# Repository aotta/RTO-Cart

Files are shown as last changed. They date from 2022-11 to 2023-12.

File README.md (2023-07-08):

# RTO-Cart
Redesigned T-Cart - Multicart for Mattel Intellivision based on Teensy 4.1
It work with bin file loaded on sdcard, with ram/rom mapping from .cfg files with same name in same folder.
If found the [macro] section in the .cfg files, it ask for using the Cheat's pokes (middle button) or ignore them (other button).
File navigation is done with by buttons, while playing button 1 resets the console, button 3 resets the Cart.

You probably don't need mounting the resistor near the edge for reset the console, try yourself and be sure to have a good bipolar cap at reset line in your console! ;) 

More infor on:
https://forums.atariage.com/topic/346024-intellivision-rto-multicart-new-multicart/

User manual added by courtesy of Eskimo/RKOTower

Fixed version for SECAM Intellivision (thanks to zx81zx81):
https://github.com/zx81zx81/RTO-Cart-secam

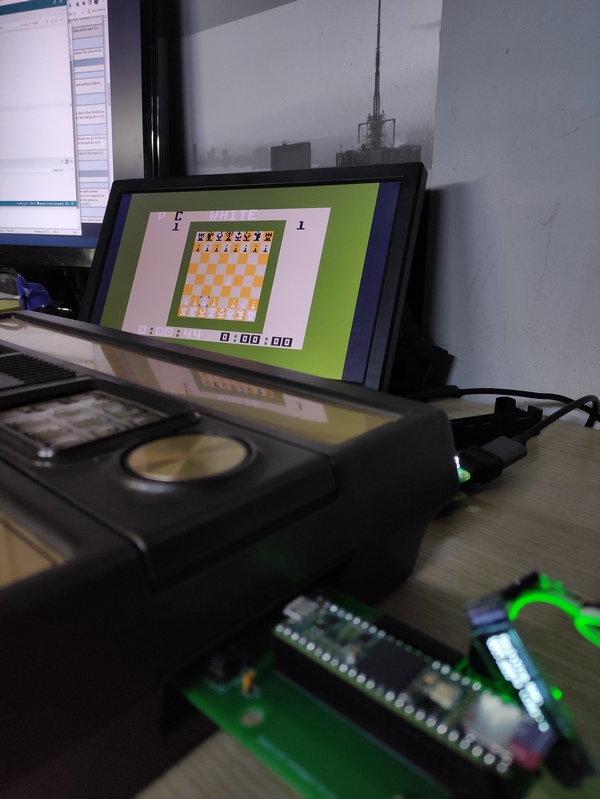
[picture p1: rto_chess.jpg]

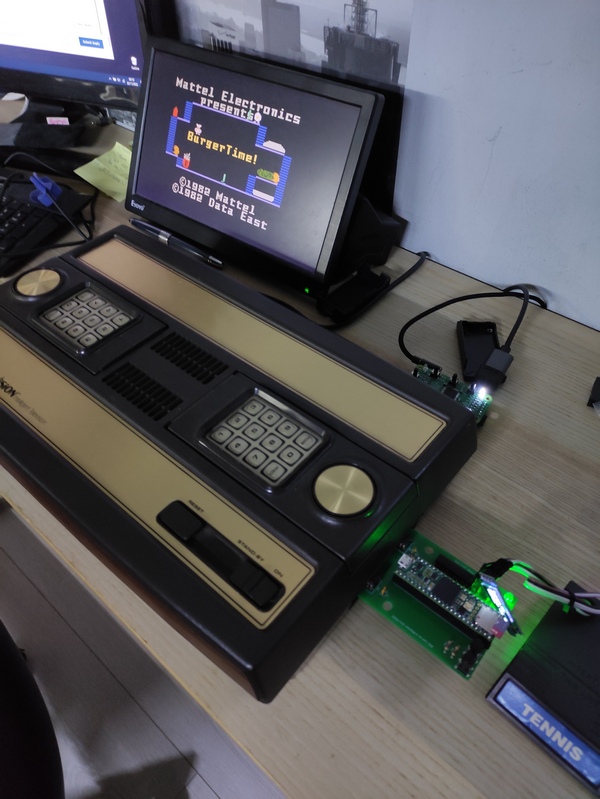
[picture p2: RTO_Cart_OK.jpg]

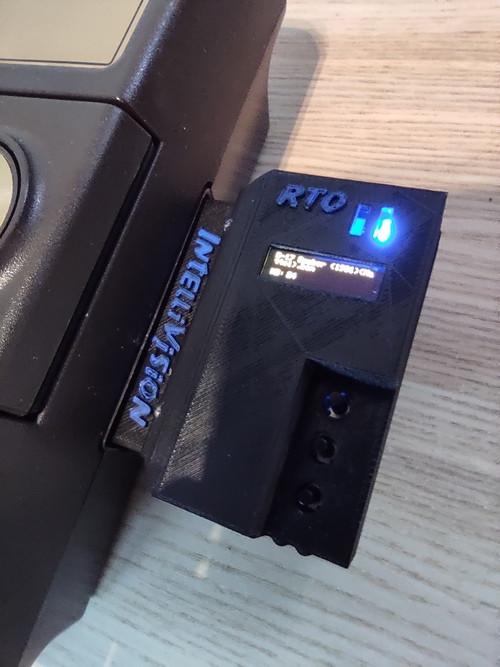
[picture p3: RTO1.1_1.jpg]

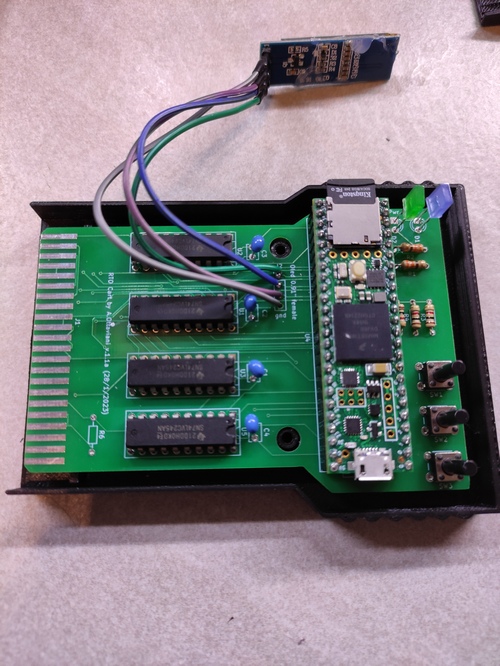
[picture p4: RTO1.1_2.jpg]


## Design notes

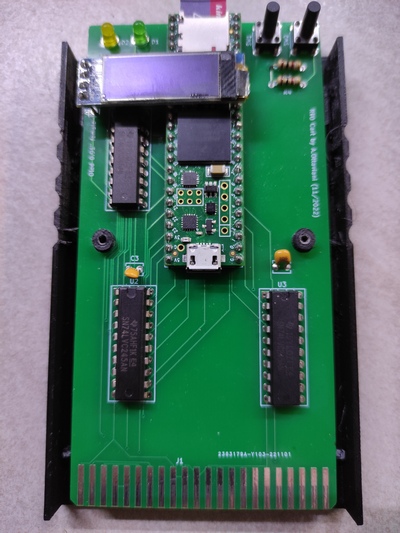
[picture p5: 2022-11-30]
rto_pcb.jpg

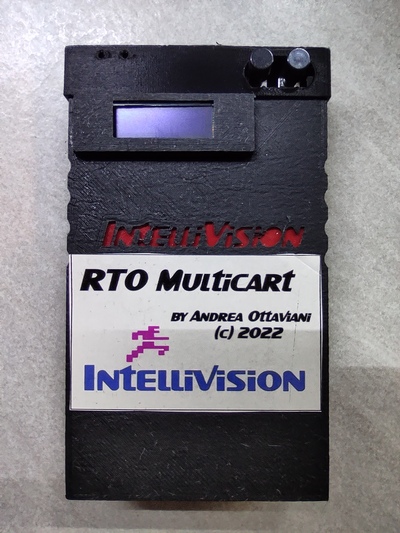
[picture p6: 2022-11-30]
cart2.jpg

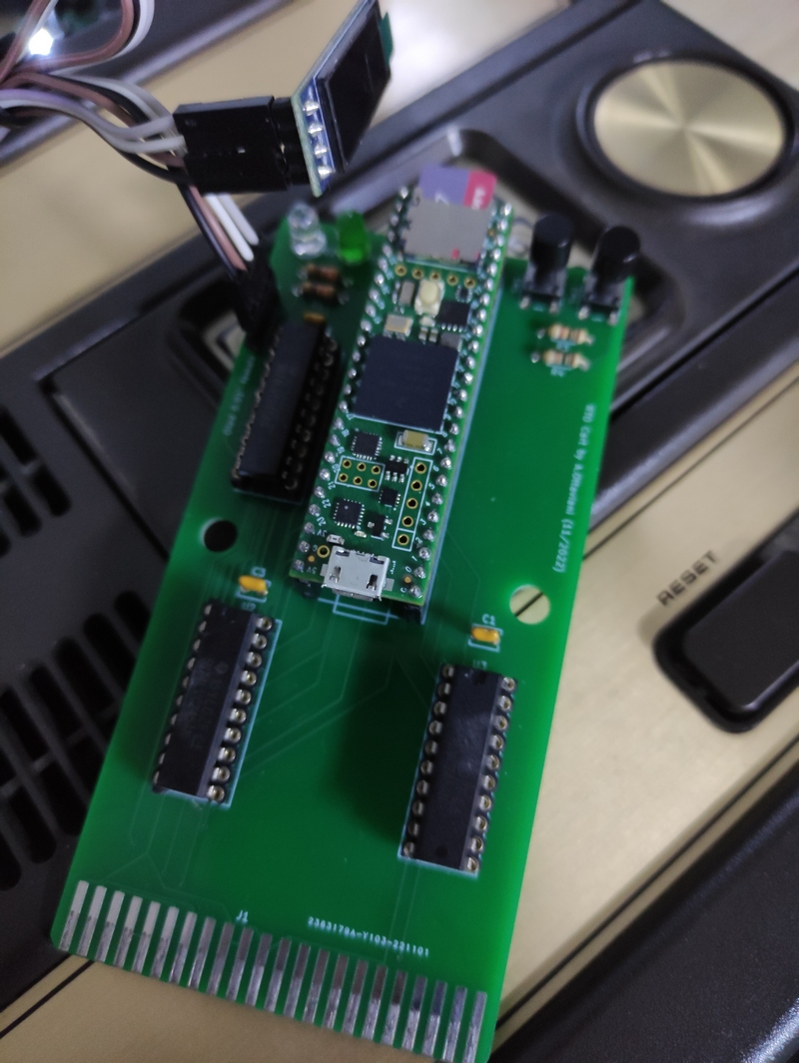
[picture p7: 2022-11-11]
RTO1.png

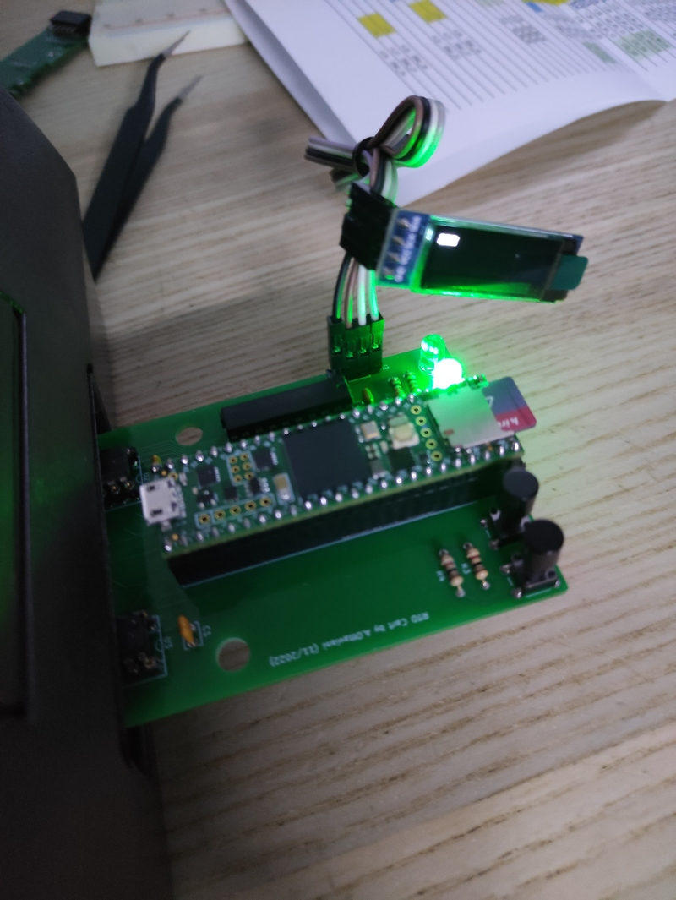
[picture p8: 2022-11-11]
RTO3.png

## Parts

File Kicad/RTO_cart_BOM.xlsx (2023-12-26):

Column1 | Column2 | Column3 | Column4 | Column5 | Column6 | Column7
Component Count: | 22
Individual Components:
Item | Qty | Reference(s) | Value | LibPart | Footprint | Datasheet
 |  | C1 | 100nF | Device:C | Capacitor_THT:C_Disc_D3.8mm_W2.6mm_P2.50mm | ~
 |  | C2 | 100nF | Device:C | Capacitor_THT:C_Disc_D3.8mm_W2.6mm_P2.50mm | ~
 |  | C3 | 100nF | Device:C | Capacitor_THT:C_Disc_D3.8mm_W2.6mm_P2.50mm | ~
 |  | C4 | 100nF | Device:C | Capacitor_THT:C_Disc_D3.8mm_W2.6mm_P2.50mm | ~
 |  | D1 | LED | Device:LED | LED_THT:LED_D3.0mm | ~
 |  | D2 | LED | Device:LED | LED_THT:LED_D3.0mm | ~
 |  | J2 | Oled 0.91" female | Connector:Conn_01x04_Male | Connector_PinHeader_2.54mm:PinHeader_1x04_P2.54mm_Vertical | ~
 |  | R1 | R220 | Device:R | Resistor_THT:R_Axial_DIN0204_L3.6mm_D1.6mm_P7.62mm_Horizontal | ~
 |  | R2 | R220 | Device:R | Resistor_THT:R_Axial_DIN0204_L3.6mm_D1.6mm_P7.62mm_Horizontal | ~
 |  | R3 | 1K | Device:R | Resistor_THT:R_Axial_DIN0204_L3.6mm_D1.6mm_P7.62mm_Horizontal | ~
 |  | R4 | 1K | Device:R | Resistor_THT:R_Axial_DIN0204_L3.6mm_D1.6mm_P7.62mm_Horizontal | ~
 |  | R5 | 1K | Device:R | Resistor_THT:R_Axial_DIN0204_L3.6mm_D1.6mm_P7.62mm_Horizontal | ~
 |  | R6 | 4K7 | Device:R | Resistor_THT:R_Axial_DIN0204_L3.6mm_D1.6mm_P7.62mm_Horizontal | ~
 |  | SW1 | SW_Push | Switch:SW_Push | Button_Switch_THT:SW_PUSH_6mm | ~
 |  | SW2 | SW_Push | Switch:SW_Push | Button_Switch_THT:SW_PUSH_6mm | ~
 |  | SW3 | SW_Push | Switch:SW_Push | Button_Switch_THT:SW_PUSH_6mm | ~
 |  | U1 | 74LVC245 | 74xx:74LS245 | Package_DIP:DIP-20_W7.62mm_Socket | http://www.ti.com/lit/gpn/sn74LS245
 |  | U2 | 74LVC245 | 74xx:74LS245 | Package_DIP:DIP-20_W7.62mm_Socket | http://www.ti.com/lit/gpn/sn74LS245
 |  | U3 | 74LVC245 | 74xx:74LS245 | Package_DIP:DIP-20_W7.62mm_Socket | http://www.ti.com/lit/gpn/sn74LS245
 |  | U4 | Teensy4.1 | teensy:Teensy4.1 | Teensy:Teensy41
 |  | U5 | 74LVC245 | 74xx:74LS245 | Package_DIP:DIP-20_W7.62mm_Socket | http://www.ti.com/lit/gpn/sn74LS245
Collated Components:
Item | Qty | Reference(s) | Value | LibPart | Footprint | Datasheet
1 | 4 | C1, C2, C3, C4 | 100nF | Device:C | Capacitor_THT:C_Disc_D3.8mm_W2.6mm_P2.50mm | ~
2 | 2 | D1, D2 | LED | Device:LED | LED_THT:LED_D3.0mm | ~
3 | 1 | J1 | 2x22 card edge connector | Evan's misc parts:2x22 card edge connector | Evan's misc parts:edge mounted 44 pin card edge connector (2x22 pin) | ~
4 | 1 | J2 | Oled 0.91" female | Connector:Conn_01x04_Male | Connector_PinHeader_2.54mm:PinHeader_1x04_P2.54mm_Vertical | ~
5 | 2 | R1, R2 | R220 | Device:R | Resistor_THT:R_Axial_DIN0204_L3.6mm_D1.6mm_P7.62mm_Horizontal | ~
6 | 3 | R3, R4, R5 | 1K | Device:R | Resistor_THT:R_Axial_DIN0204_L3.6mm_D1.6mm_P7.62mm_Horizontal | ~
7 | 1 | R6 | 4K7 | Device:R | Resistor_THT:R_Axial_DIN0204_L3.6mm_D1.6mm_P7.62mm_Horizontal | ~
8 | 3 | SW1, SW2, SW3 | SW_Push | Switch:SW_Push | Button_Switch_THT:SW_PUSH_6mm | ~
9 | 4 | U1, U2, U3, U5 | 74LVC245 | 74xx:74LS245 | Package_DIP:DIP-20_W7.62mm_Socket | http://www.ti.com/lit/gpn/sn74LS245
10 | 1 | U4 | Teensy4.1 | teensy:Teensy4.1 | Teensy:Teensy41

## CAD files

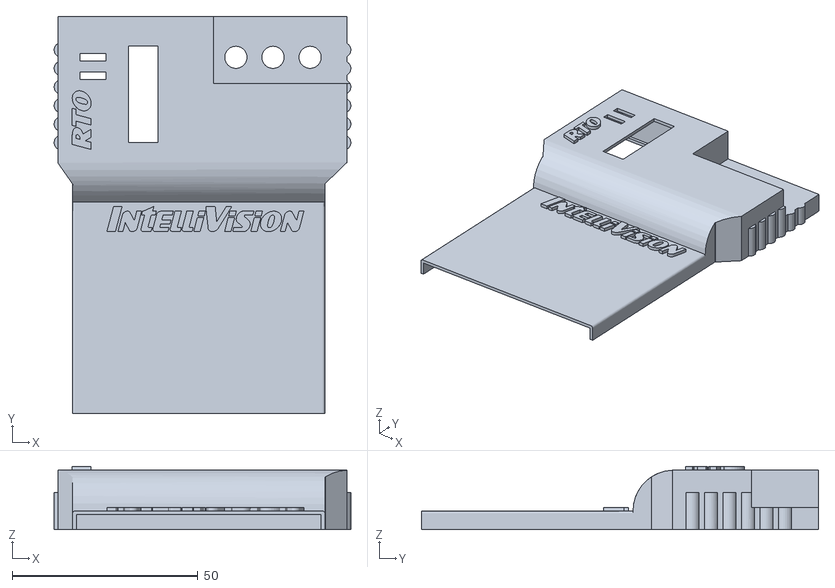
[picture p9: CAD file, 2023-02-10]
3DModel/RTO11a_Cart_TOP.stl
80.0 x 107.0 x 17.0

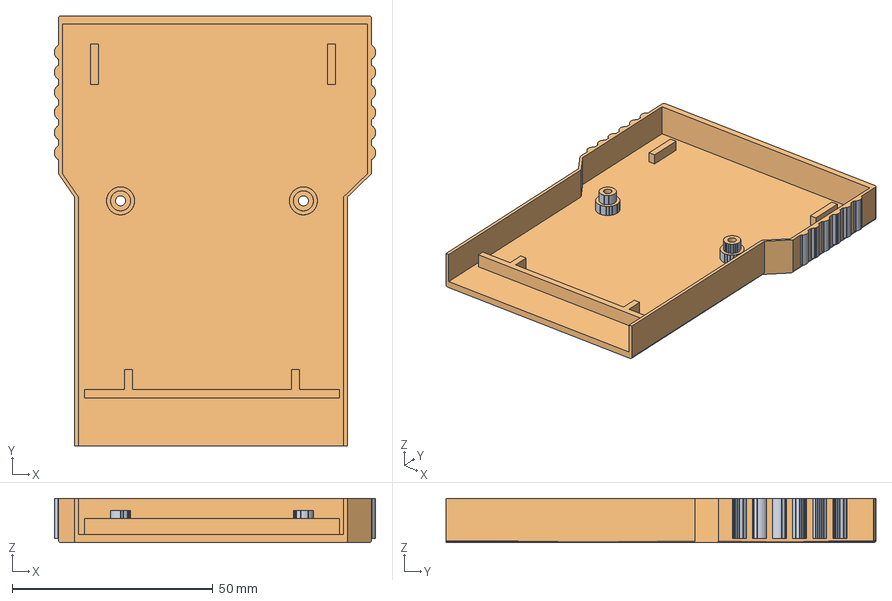
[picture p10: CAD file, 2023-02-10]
3DModel/RTO11a_Cart_Bottom.FCStd
80.0 x 107.0 x 11.0 mm
Bot__final
Refined_Mesh_Solid_81622
Bot__final (Meshed)

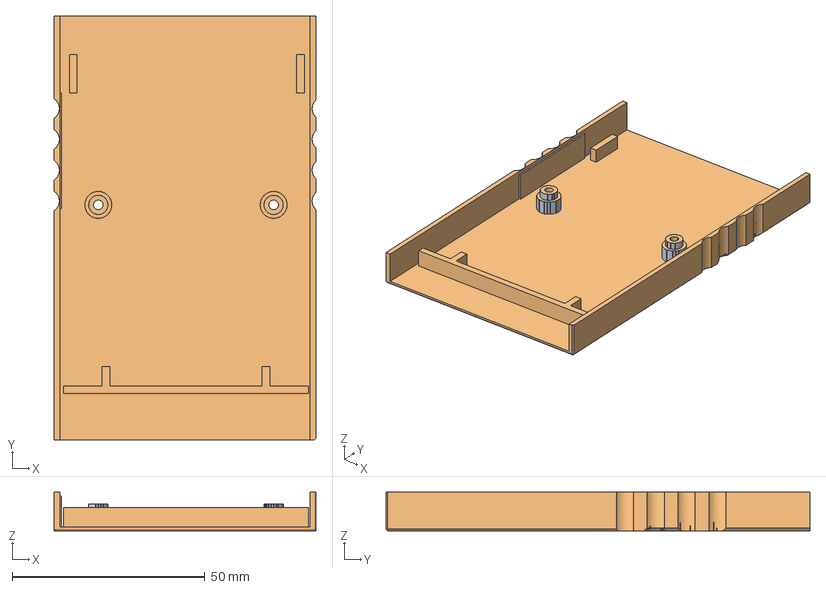
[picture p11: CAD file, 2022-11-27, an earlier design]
old ver/3DModel/RTO_Cart_Bottom.FCStd
68.0 x 110.0 x 10.0 mm
Refined_Mesh_Solid_77860
Chamfer003 (Meshed)

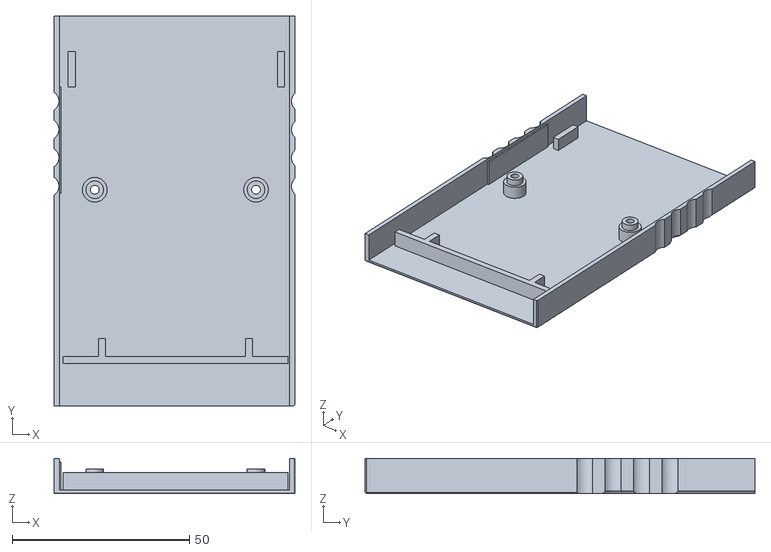
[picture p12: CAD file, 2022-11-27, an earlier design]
old ver/3DModel/RTO_Cart-BOT.stl
68.0 x 110.0 x 10.0

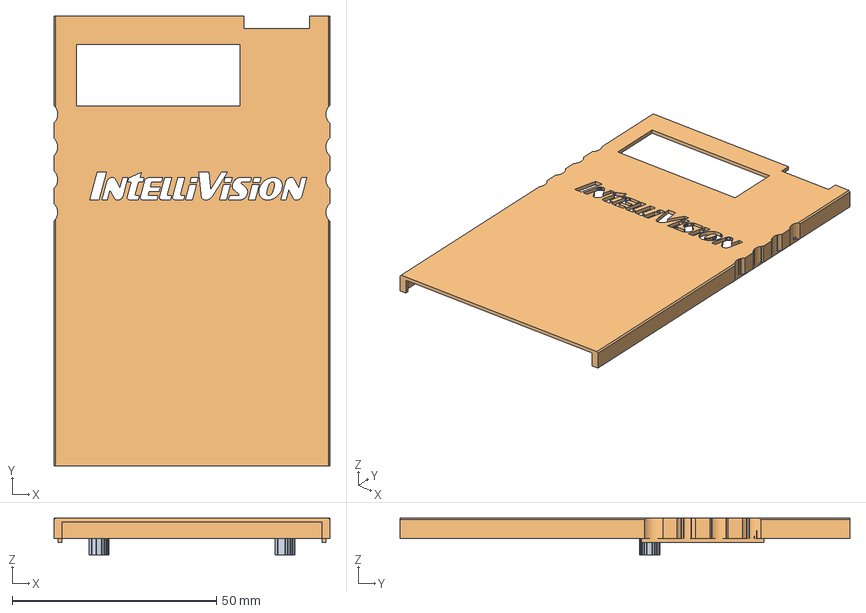
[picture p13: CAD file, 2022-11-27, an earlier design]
old ver/3DModel/RTO_Cart_TOP.FCStd
67.5 x 110.0 x 9.00 mm
Refined_Mesh001_Solid_54728
Chamfer (Meshed)

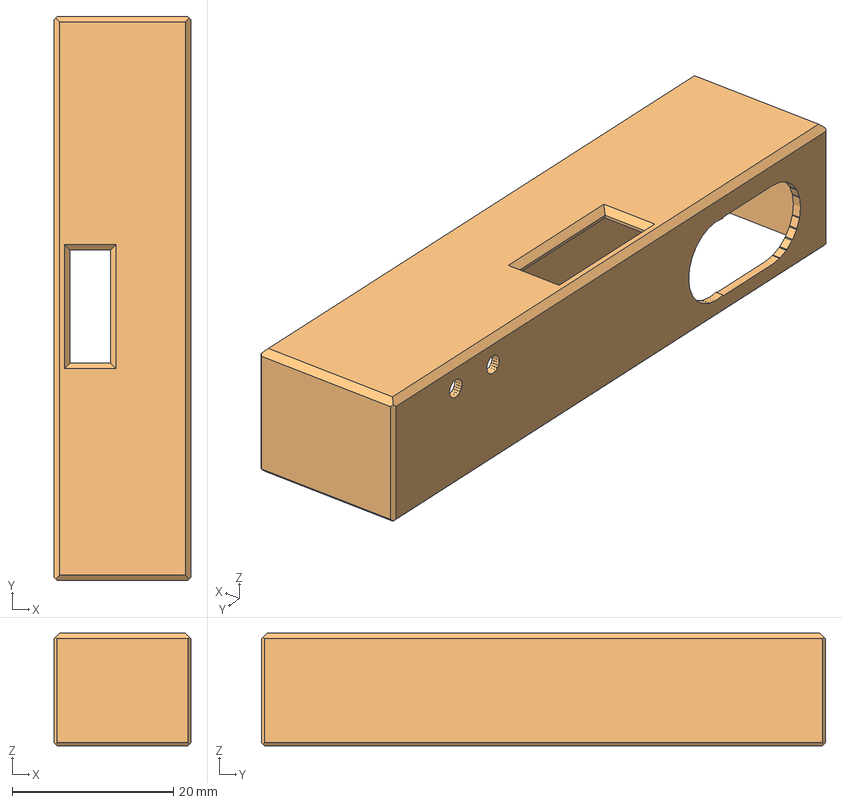
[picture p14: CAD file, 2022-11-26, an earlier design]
old ver/3DModel/RTO_Cart_CUP.FCStd
17.0 x 70.0 x 14.0 mm
Refined_Mesh_Solid_77090
Cut006 (Meshed)

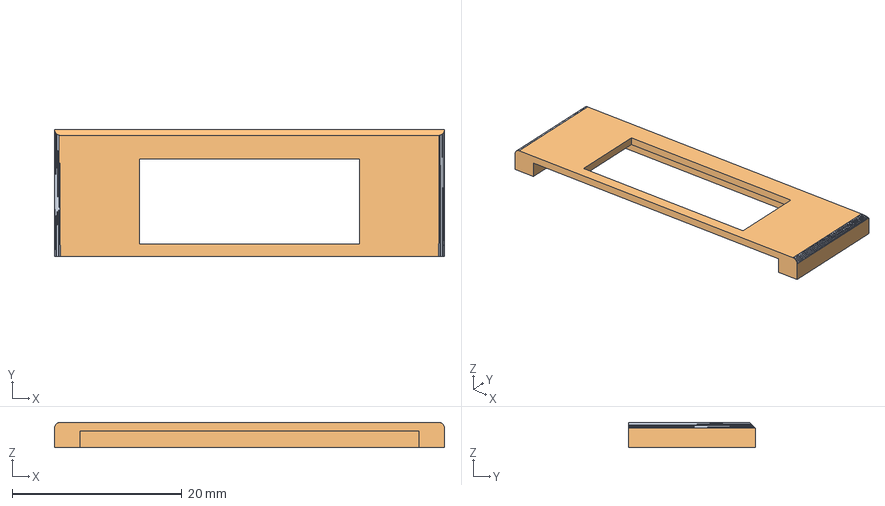
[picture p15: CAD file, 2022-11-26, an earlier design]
old ver/3DModel/RTO_Cart_LCD.FCStd
46.0 x 15.0 x 3.00 mm
Refined_Mesh_Solid_99120
Cut002 (Meshed)

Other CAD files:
3DModel/RTO11a_Cart_Bottom.stl
old ver/3DModel/RTO_Cart_CUP.stl
old ver/3DModel/RTO_Cart_LCD.stl
old ver/3DModel/RTO_Cart_TOP.stl

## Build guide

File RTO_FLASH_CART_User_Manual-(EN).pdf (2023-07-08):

### RTO FLASH CARTRIDGE USER MANUAL

Cartridge Design by Andrea Ottaviani Package Design by Alessandro
User Manual by Eskimo/RKOTower

The hardware cartridge "Intellivision RTO Flash Cart" (henceforth referred to as RTO) allows Program/Game files to be loaded on the Intellivision console; these files are "Cartridge Dumps" i.e. transfers of the programs contained in the ROMs of the Intellivision cartridges.
These files must be stored on a micro SD card, which is inserted into the compartment located to the left of the RTO, and the latter will be inserted into the cartridge port of the console.

TECHNICAL FEATURES

-) Supported console : Mattel Intellivision

-) Compatible type of files : .BIN + .CFG

-) RTO reads files stored on a micro SD

-) Compatible media : micro SD Card from 1 Gb to 32 Gb - FAT and FAT32 formatting

-) Compatible Intellivision Console : PAL/NTSC or SECAM

-) Operations of searching and loading files by three Push Buttons located on the RTO cartridge

-) Titles must be placed in the Root of the micro SD card or, to sort Titles, inside folders placed in the Root of the micro SD card, for example to sort them by alphabetically, by genre etc. - Sub-folders can NOT be used.

-) It needs to be stored in the Root of the micro SD the basic configuration file "0.cfg". See Appendix

-) Folders and file names : Compatible with Long Names, max 45 Characters + extension for files

-) RTO shows the list of folders and files on the OLED display

-) Two LEDs are the indicators of RTO cartridge operation.

-) Direct power supply from the console's cartridge port

IMPORTANT

All connections and disconnections, both electrical and mechanical, must be made with the equipment off and the cables not connected to the mains electrical outlets.

Do not use liquids to clean the RTO cartridge, but only cloths made of antistatic material.The RTO cartridge is composed of electronic parts and its casing is made of PLA or ABS plastic material.

Do not press on the small window that houses the OLED Display, this is a delicate component and pressure can damage it and cause it to come out of its housing creating further damage to other electronic components that are inside the RTO cartridge.

Do not disassemble the RTO cartridge and do not make any repair attempts; these tasks should only be carried out by qualified personnel.

Be careful not to spill liquids on the RTO cartridge, in case of accidental spillage of liquids, do not insert the RTO cartridge into the console, and in case it is inserted, remove the plug from the electrical outlet immediately, and dry the RTO cartridge. Before connecting the RTO cartridge make sure it is completely clean and dry, otherwise repeat the cleaning and drying steps.

The User of the RTO Cartridge is solely responsible in case of damage to People, Animals and Property occurred with the use of the RTO Cartridge; the Hardware Designer, the Author of the Manual and the Vendors are not responsible in case of damage to People, Animals and Property occurred with the use of the RTO Cartridge.

By using the RTO Flash Cartridge for Intellivision, the User agrees to the above conditions.

INTELLIVISION CONSOLE CONNECTION

The RTO cartridge should be inserted directly into the right cartridge port of the console.
Insert the RTO cartridge into the console's cartridge port with the side where the text and LEDs are located facing up.

Tip : Place under the RTO cartridge a stand, a support base, which makes the RTO secure and rigidly stable in its position, this for when Push Buttons are pressed during operations.
This holder prevents the RTO cartridge from flexing with finger pressure on the Push Buttons, thus preventing force on the Intellivision connector contacts and the connector itself.
Bending the cartridge could create false contacts and malfunctions, and in the long run could also damage the Intellivision connector or the RTO cartridge itself, or both.
This expediency is advisable because the RTO works through buttons located on the cartridge itself, whereas standard cartridges are inserted into the port but have no buttons to operate.

INSTRUCTIONS ON THE USE OF RTO CARTRIDGE

Using a Personal Computer (the following directions consider a PC with Windows O.S.) copy the program files with the extension .BIN + .CFG to a micro SD card.
You can create folders (only on the Root) to search and sort your Files, e.g. to sort them by genre, type etc. but you CANNOT create sub-folders, the files can be stored either in the Root or in a folder on the micro SD.
The .BIN file must always be associated with a .CFG file, and they must have the same name.

Example : "Burgertime.bin" + "Burgertime.cfg"

NOTE : In case you transfer only the .BIN file without the .CFG configuration file, then the RTO cartridge, not finding the latter, will use, by default, the configuration file "0.cfg" , which must be transferred to the Root of the micro SD, and obviously it may or may not be compatible with your .BIN file.

In general, the "0.cfg" configuration file is compatible with the vast majority of Roms, but not all.

If the RTO cartridge does not find the associated configuration file neither the "0.cfg" file, then it will not be able to run the Program/Game.

The .BIN file contains the "Dump" of the Roms, i.e., all Program/Game data, while the .CFG file contains information on how the various data areas of the Roms should be allocated in the Intellivision's memory map.

Without this important file, the RTO cartridge would not know where to place the contents of the Rom and would not start the Program/Game.

Obviously the .CFG file must contain the correct data, otherwise RTO cannot run the Program/Game.

There are .CFG files that in addition to containing the parameters for Rom allocation, contain additional data, namely "Hacks".

For example, these "Hacks," may have been added to activate the Infinite Lives on a game, or increase the running time of a "Stage," to activate the character's invulnerability, to select which "Stage" to start from, and so on.

In this case the RTO cartridge recognizes the presence of the "Hacks" added in the .CFG file, and asks if you want to activate them or not.

To activate any "Hacks" you press PB 2 on the RTO, but if you want to start the standard Game without "Hacks" you press one of the other two Push Buttons, either PB 1 or PB 3; the detailed explanation of the RTO Push Buttons and their location can be found in the following paragraphs.

NOTE : The .CFG files containing the "Hacks" are created by console enthusiasts, and made generally for use on Intellivision Computer Emulators, so they may also not be fully compatible with the Intellivision console and RTO.

Tip : For transferring the Files to the micro SD, it is preferable to keep a folder with all Programs/Games on the PC and select all Titles and Folders, then right-click on the first Title or Folder in alphabetical order and select "copy," then place on the micro SD card and select "paste" to begin the transfer.

This procedure makes sure to transfer all Files and Folders by copying them in alphabetical, order so that they are found in the same order on the OLED display of the RTO cartridge.

Similarly when you want to add one or more Programs/Games, the best procedure is to copy them to the folder on the PC that contains the ones already transferred previously, then wipe, i.e., delete all the contents of the micro SD card and transfer all the contents from the folder of the PC to the micro SD card as described above.

This avoids ending up with the latest titles added at the top of the list, or in the middle of existing ones, thus maintaining the alphabetical order on the OLED display of the RTO.

It may happen that by adding Titles on the micro SD that already contains others, these added Titles will be shown first on the OLED display by the RTO.

Of course, there is nothing to prevent you from adding titles progressively and proceeding as you like.

HOW TO NAME FILES

The RTO cartridge handles long names, but in order to avoid non-recognition of a title, it is strongly recommended that titles be simplified as much as possible, for example by avoiding the "Space" between names, and instead use the "Minus - " sign and "Underscore _ ", these symbols are fully supported by the RTO cartridge.
Avoid to include symbols such as "Dot", "Apostrophe", "Comma", "Exclamation/Question marks", "Asterisks", etc. etc. and keep the file name as short as possible; Names up to 45 characters long are supported.

Example : a title such as "Masters of the Universe-The Power of He-Man! (1983) (Mattel).bin" would be best reduced to the following "Masters_o_t_Universe-T_P_o_He-Man-(1983).bin"; the exclamation mark was removed, then simplified and shortened, but it still remains understandable, especially for fans of the Intellivision console who are very familiar with all the titles produced.
You can still leave the original title unchanged without any simplification, as you prefer, always respecting the maximum number of 45 characters
Only in the case where, due to some unsupported character, or a bad combination of characters, the title does not appear on the OLED display of the RTO cartridge (in this case a blank space appears when scrolling forward and backward through the titles) then it can be decided to simplify the title to make it compatible.

Once you have completed preparing the micro SD card you can insert it into the slot located on the left side of the RTO; the micro SD should be inserted with the label facing up, and the electrical contacts facing down.

Now you can insert the RTO into the right cartridge slot of the Intellivision console and then turn on the TV or Monitor and the console.

FUNCTIONS DESCRIPTION OF RTO PUSH BUTTONS

The RTO cartridge has three Push Buttons (PB 1 – PB2 – PB3) to operate and to perform various functions, the diagram below shows the location and the Push Buttons Position :

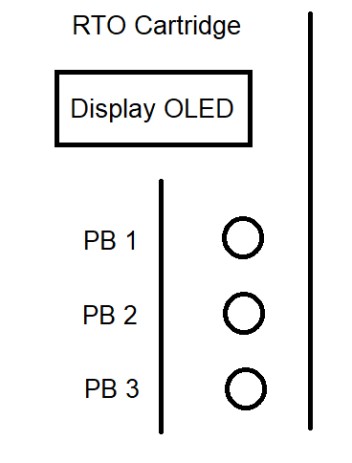
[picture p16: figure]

Functions of the three Push Buttons before starting a Rom on the Intellivision Console

PB 1 - Forward Scrolling Titles and Folders

PB 2 - Enter/Exit a Folder - Starts the selected file (NOTE : to exit from a Folder, use PB 1 or PB 3 to display two exit points with the following characters : " . . Kb:0 " then press PB 2

PB 3 - Backward Scrolling Titles and Folders

Functions of the three Push Buttons while a Program/Game is running on the Console

PB 1 - Reset Intellivision Console (NOTE : If Pushing PB 1 the screen on the TV/Monitor turns black, it means the “Capacitor” on the Reset line of your Intellivision is defective, and to restart the Program/Game that was running you have to press, in addition, the Reset Button on the Intellivision console)

PB 2 - Not Used

PB 3 - Reset Cartridge RTO

When the TV/Monitor and Intellivision console are turned on, the following condition is observed :
The TV/Monitor shows the Main Screen " RTO - Cart Please Select a Game ".
The OLED Display shows the following : " Press a Button on RTO ", use the PB 1 and PB 3 buttons to navigate back and forth through the Titles and Folders, in order to position on the desired Title.
If the Main Screen image does not appear on the TV/Monitor and you have a black screen instead, and also pressing the PB1 and PB 3 buttons they do not work, it means that your console has the "Capacitor" on the "Reset" line defective.

This is not a problem, in fact simply pushing the "Reset" button on the Intellivision, the RTO will be activated, and the Main Screen of the RTO cartridge will appear on the TV/Monitor : " RTO - Cart Please Select a Game ", now you can scroll through the Titles as reported above.

Pushing PB 2 starts a Program/Game or enters in a Folder.

The OLED Display shows the "filename.bin," while the "filename.cfg" is not displayed because it is only for the system and its display has no practical use.

On the OLED display of the RTO in addition to the "filename.bin" the line below shows the size of the ROM in Kb.

Pushing PB 2 will load the ROM into the console and start it.

The OLED display will show the following message : "Emulating ROM : filename.bin" and the Program/Game will start.

If, same as before, the TV/Monitor will remain black without displaying anything, (again due to the defective "Capacitor" mentioned above), to start the Program/Game you must push the Reset button on the Intellivision console.

At this point the control moves to the Intellivision console and you can use all the functions of the "Gamepads" as an original cartridge had been inserted.

By pressing the Reset button on the Intellivision console, the Program/Game will restart, remaining present at all times and behaving as an original cartridge had been inserted.

The same thing is done by pressing PB 1 on the RTO; this button, while the Program/Game is running, has the same function as the Reset button of the Intellivision console.

Pressing the PB 3 instead, while the Program/Game is running, will reset the RTO and remove the Program/Game from the Intellivision console, on the OLED display will appear : "Press a button on RTO", the TV/Monitor will turn black showing nothing more.

At this point the Program/Game is quit and you can proceed to load another one.

In case your Intellivision has the defective "Capacitor", in order to load a new Program/Game you need to do an additional step, in fact pressing any of the 3 buttons nothing happens, then you have to push the Reset button on the Intellivision console, so the Main Screen " RTO - Cart Please Select a Game " will appear on the TV/Monitor.

You can then repeat the above mentioned operations to load a new Program/Game.

INTELLIVISION FILE FORMATS

There are a few formats of the files extracted from Intellivision cartridges, following the three most important ones. All the Cartridges Dumps at least they are available on one of these three formats :

"filename.BIN" | "filename.INT" | "filename.ROM"
1. "filename.BIN" is the classic binary file extracted from the roms contained in Intellivision cartridges, this type of file needs the configuration file "filename.CFG" as described above.
2. “filename.INT” also this is a binary file exactly the same as the previous one, only the extension changes, this type of file needs the configuration file "filename.CFG" as described above. This type of extension was adopted on the Intellivision Emulators, which, probably having to run also on PCs, with Windows O.S., it does not like extension conflicts, in fact the extension .BIN, was already in use on these O.S., and using it could have created association problems with other programs.
3. filename.ROM is the binary file with configuration data included, that is the contents of the "filename.CFG" file, so this type of file does not need the configuration file having it already internally.

As described in the technical features of the RTO cartridge, the only format supported is .BIN, in fact if we transferred files with the extensions .INT and .ROM to the micro SD they would not be showed on the OLED display, and in any case would not be handled.
Let's see how we can handle these two formats and make them compatible with the RTO cartridge.
| filename.INT

For this format the procedure is very simple, just rename the extension from .INT to .BIN
Example : "burgertime.int" renaming the extension will become "burgertime.bin", having done this simple step we treat it exactly like a .BIN file.

filename.ROM

As described before this is an "Embedded" file that it includes the two files "filename.BIN" and "filename.CFG" in the .ROM file.
In order to use it on the RTO cartridge, it is necessary to extract the two files and save them separately.
To do this we use a program that runs on the Windows O.S. called
"rom2bin.exe"
The program can be downloaded from the following link : http://spatula-city.org/~im14u2c/intv/ where you can find the SDK (Software Development Kit) of the Intellivision emulator "jzintv".
The program, (once unpacked the downloaded file, currently named "jzintv-20200712-win32-sdl2.zip"), it’s inside the folder "bin/" .
This program is a converter, which converts a .ROM file into two separate .BIN and .CFG files
Its use is very simple: copy into a folder the program "rom2bin.exe" and the files you want to convert, then drag and drop the file "namefile.rom" on the program file "rom2bin.exe", and you will get two separate files "namefile.bin" and "namefile.cfg". These two files are now compatible with the RTO cartridge.

IF A PROGRAM/GAME FILE DOES NOT RUN ON RTO

We can face the condition of having transferred to the micro SD card a Program/Game that does not start, some reasons may cause the issues , below we try to find the solution.

1. The names of the files are not the same and as a result the RTO cannot find the configuration file.
Solution : rename the .CFG file exactly like the .BIN file.
2. The two .bin and .cfg files are located in a subfolder.
Solution : move the two files to the root of the micro SD card or into a root folder and delete the sub folder that contained them, it has no use.
3. The .ROM file was converted incorrectly and the two .BIN and .CFG files are damaged.
Solution : repeat the file conversion.
4. Even if the file has the extension .BIN it is not a binary .BIN or even it’s not an Intellivision Rom. Solution : the file is not usable
5. The .BIN file or the .CFG file is corrupt.
Solution : the file is not usable
6. The .CFG file is incorrect or it’s only compatible with the PC Emulators and not with the RTO cartridge. Solution : correct and edit the .CFG file.

CORRECTING AND EDITING .CFG FILES

The .CFG files originated primarily for use with Intellivision Emulators on Computers, they are needed to provide information on how to allocate and define the memory for ROMs and RAMs.
As Emulators evolved, the configuration files also began to change by adding information that was useful to a specific Emulator.
Today there are different types of .CFG files for the same Program/Game, but with different contents and parameters (Obviously except memory allocation parameters that must be maintained).
Let's look at a practical example of a standard .CFG file and the same one with a simple difference :
"filename.cfg" Version 1 | "filename.cfg” Version 2
[mapping] | [mapping]
$0000 - $1FFF = $5000 | ECS
| $0000 - $1FFF = $5000

Both files are correct and they work, but the Version 1 is compatible with all emulators and will certainly not give any problems even with RTO, but in the Version 2 we can see the addition of a line with "ECS" , which informs that the Program/Game needs additional peripherals to be used.
Probably this second configuration file was created for an Emulator that has the feature to use this additional line, and it is possible that on other Emulators it could create compatibility problems.
The RTO cartridge recognizes Version 1 memory mapping, so with the configuration file containing the "ECS" information it will not start the Program/Game, so we have to change it to the Version 1 by deleting the line containing "ECS"

To better understand how a configuration file is composed we use the following example :

"Burgertime.cfg"

[mapping]
$0000 - $1FFF = $5000 ; 8K to $5000 - $6FFF $2000 - $2FFF = $D000 ; 4K to $D000 - $DFFF $3000 - $3FFF = $F000 ; 4K to $F000 - $FFFF

"Burgertime_(Hack).cfg"

[mapping]
$0000 - $1FFF = $5000
[memattr]
$D000 - $DFFF = ROM 16
$F000 - $FFFF = ROM 16
[macro]
p 633a 34 ; Infinite peppers (both players)
p 51f9 34 ; Infinite lives (both players)
and so on with more lines |

These are two configuration files of the same game "Burgertime", the first file is standard and gives the memory mapping information, the second one in addition to the mapping includes the "Hacks", they are placed after the line “[macro]”.
Both files are compatible with the RTO, in fact, as described above the RTO can activate the "Hacks".
It is mandatory that before the line with “[mapping]”, must not be present any lines of text or parameters, if they were present, the Program/Game would not be executed, if you encounter this situation delete all lines placed before “[mapping]”.

In the following example you can see a rather complex "Burgertime" configuration file, which contains a lot of information and "Hacks," this file would not work on the RTO cartridge.
This file is compatible with Computer Emulators, which can handle multiple configuration and information parameters.
To make it compatible with the RTO cartridge, it is necessary to delete all lines shown in "Underlined" and then start the file with the text highlighted in bold [mapping].
;;;BurgerTime! (Trainer) (1982) (Mattel) [h].cfg | DELETE FROM HERE
;;;20210616gernotschrader
[vars]
kc_compat = 0
name = "BurgerTime!, Trainer (128 Cooks)" short_name = "BurgerTime!, Trn."
author = "Data East / Ray Kaestner"
publisher = "Mattel Electronics"
release_date = 1982
; | TO HERE
[mapping] | KEEP FROM HERE
$0000 - $1FFF = $5000
;
[memattr]
$9000 - $91FF = ROM 16
;
[macro]
p 500a 0 ; date / title $9000 ($5040) p 500b 90 ; "
p 5013 4 ; border color
;
p 51ce 7f ; reserve Peter & Pepper (4) | TO HERE

To correct or edit a file "filename.cfg" use a Computer (the following consider a PC with Windows O.S.) with a "Text Editor," "Notepad" will do just fine.
Temporarily add .TXT extension to the .CFG file, then the file "filename.cfg" will become "filename.cfg.txt", the PC will open a window and warn that by changing the extension the file may become unusable, press "OK" to accept the extension change. Load the file with the "Text Editor" and proceed to edit the configuration file, then save, close the "Text Editor" and finally delete the .TXT extension that was added, your configuration file is ready to be tested.

APPENDIX

Basic Configuration file “0.cfg” :

You can find the “0.cfg” on the web or you can write it by yourself with a “Text Editor”; following the lines to type on the Editor :

[mapping]
$0000 - $1FFF = $5000 ; 8K to $5000 - $6FFF
$2000 - $2FFF = $D000 ; 4K to $D000 - $DFFF $3000 - $3FFF = $F000 ; 4K to $F000 - $FFFF

When done, save the file as : 0.cfg

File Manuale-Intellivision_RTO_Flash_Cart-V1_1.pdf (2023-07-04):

### MANUALE CARTUCCIA RTO FLASH CART PER INTELLIVISION Progetto Hardware e Codice di Andrea Ottaviani Manuale di Eskimo / RKOTower Versione 1.1

La cartuccia hardware “Intellivision RTO Flash Cart” (da ora in avanti denominata RTO) permette di caricare sulla console Intellivision i files Programmi/Giochi; questi files sono “Dump” di cartucce (Cartridge Dump) cioè trasferimenti dei programmi contenuti nelle ROMs delle cartucce Intellivision.
Questi files devono essere memorizzati su scheda micro SD, la quale viene inserita nel vano che si trova a sinistra della RTO e quest’ultima verrà successivamente inserita nella porta cartucce della console.

CARATTERISTICHE TECNICHE

-) Console supportata : Mattel Intellivision
-) Tipo di files supportati : .BIN + .CFG
-) Supporto lettura files su micro SD
-) Media compatibili : micro SD Card da 1 Gb a 32 Gb – Formattazione FAT e FAT32
-) Supporto Console Intellivision PAL / NTSC o SECAM
-) Operazioni di ricerca e caricamento files tramite tre pulsanti posti sulla cartuccia
-) Supporto Titoli posizionati nella radice “Root” della scheda micro SD oppure all’interno di cartelle poste nella radice “Root” della scheda micro SD, per ordinare i Titoli ad esempio in ordine alfabetico, per genere etc. NON si possono utilizzare sotto cartelle.
-) Memorizzare nella radice “Root” della micro SD il file di configurazione base “0.cfg”
-) Supporto nomi cartelle e files : Compatibile con Nomi Lunghi, max 45 Caratteri + estensione per i files
-) Visualizzazione lista delle cartelle e dei files sul Display OLED della RTO
-) Due LEDs sono gli indicatori del funzionamento della cartuccia RTO
-) Alimentazione diretta dalla porta cartucce della console

IMPORTANTE

Tutte le connessioni e disconnessioni sia elettriche che meccaniche devono essere eseguite con le apparecchiature spente ed i cavi non connessi alle prese elettriche di rete.
Non usare liquidi per la pulizia della cartuccia RTO, ma solo panni in materiale antistatico.
La cartuccia RTO è composta da parti elettroniche ed il suo involucro è costituito da materiale plastico PLA.
Non premere sulla finestrella che ospita il Display OLED, questo è un componente delicato e la pressione lo può danneggiare e farlo uscire dalla propria sede creando ulteriori danni ad altri componenti elettronici che si trovano all’interno della cartuccia RTO.
Non smontare la cartuccia RTO e non eseguire tentativi di riparazione, questi interventi devono essere eseguiti solo da personale qualificato.
Fare attenzione a non versare liquidi sulla cartuccia RTO, nel caso di versamento accidentale di liquidi, non inserire la cartuccia RTO nella console, e nel caso fosse inserita togliere immediatamente la spina dalla presa elettrica, ed asciugare la cartuccia RTO.
Prima di collegare la cartuccia RTO assicurarsi che sia completamente pulita ed asciutta, diversamente ripetere le operazioni di pulizia ed asciugatura.
L’Utilizzatore della Cartuccia RTO è l’unico responsabile in caso di danni a persone, animali e cose avvenuti con l’uso della Cartuccia RTO; il Progettista Hardware, l’Autore del Manuale ed i Venditori non sono responsabili in caso di danni a persone, animali e cose avvenuti con l’uso della Cartuccia RTO.
Utilizzando la Cartuccia RTO Flash Cart per Intellivision, l’Utente accetta le sopra menzionate condizioni.

CONNESSIONE ALLA CONSOLE INTELLIVISION

La cartuccia RTO va inserita direttamente nella porta cartucce destra della console.
Inserire la cartuccia RTO nella porta cartucce della console con il lato dove si trovano le scritte ed i LEDs rivolto verso l’alto.
Suggerimento : Posizionare sotto la cartuccia RTO un supporto, una base di appoggio, che rende sicura e rigidamente stabile la RTO nella sua posizione, questo per quando vengono premuti i pulsanti durante le operazioni.
Questo supporto impedisce che la cartuccia RTO si fletta con la pressione delle dita sui pulsanti evitando così di forzare sui contatti del connettore dell’Intellivision e sul connettore stesso.
La flessione della cartuccia potrebbe creare falsi contatti e malfunzionamenti e a lungo andare potrebbe anche danneggiare il connettore dell’Intellivision o la cartuccia RTO stessa, o entrambi.
Questa accortezza e consigliabile in quanto la RTO lavora tramite pulsanti posizionati sulla cartuccia stessa, mentre le cartucce standard vengono inserite nella porta ma non hanno pulsanti dove operare.

ISTRUZIONI SULL’UTILIZZO DELLA CARTUCCIA RTO

Tramite un Personal Computer (le indicazioni che seguono prendono in considerazione un PC con S.O. Windows) copiare i files programma con estensione .BIN + .CFG su una scheda micro SD.
Potete creare delle cartelle per contenere i vostri titoli, ad esempio per suddividerli per genere, tipologia etc. ma NON potete creare sotto cartelle, i files possono essere memorizzati o nella radice “Root” o in una cartella della micro SD. Il file .BIN deve essere sempre associato ad un file .CFG essi devono avere lo stesso nome.

Esempio : “Burgertime.bin” + “Burgertime.cfg”

NOTA : Nel caso si trasferisca solo il file .BIN senza il file di configurazione .CFG allora la cartuccia RTO, non trovando quest’ultimo, userà di “default” il file di configurazione “0.cfg” , che deve essere trasferito nella radice “Root” della micro SD, ed ovviamente esso può essere o meno compatibile con il vostro file .BIN.
In generale il file di configurazione “0.cfg” è compatibile con la grande maggioranza delle Roms, ma non con tutte.
Se la cartuccia RTO non trova il file di configurazione associato e non è presente neanche il file “0.cfg” allora non potrà eseguire il Programma/Gioco.

Il file .BIN contiene il “Dump” delle Rom, cioè tutti dati del Programma/Gioco, mentre il file .CFG contiene le informazioni su come le varie aree dati delle Rom devono essere allocate nella mappa di memoria dell’Intellivision. Senza questo importante file la cartuccia RTO non saprebbe dove posizionare il contenuto della Rom e non farebbe partire il Programma/Gioco.
Ovviamente il file .CFG deve contenere i dati corretti, diversamente RTO non può eseguire il Programma/Gioco.

Esistono dei file .CFG che oltre a contenere i parametri per l’allocazione delle Rom, contengono dei dati aggiuntivi, e precisamente degli “Hack”.
Questi “Hack”, possono essere stati aggiunti per attivare ad esempio le Vite Infinite di un gioco, oppure aumentare il tempo di percorrenza di uno “Stage”, attivare l’invulnerabilità del personaggio, selezionare da che “Stage” iniziare etc. In questo caso la cartuccia RTO riconosce la presenza degli “Hack” aggiunti nel file .CFG e chiede se li volete attivare oppure no.
Per attivare gli “Hack” eventualmente presenti si preme il pulsante 2 sulla RTO, se invece si vuole fare partire il Gioco standard senza “Hack” si preme uno degli altri due pulsanti o 1 oppure 3; la spiegazione dettagliata dei pulsanti della RTO e la loro posizione si trova nei paragrafi successivi.
NOTA : I file .CFG che contengono gli “Hack” sono creati da appassionati della console, e realizzati generalmente per essere utilizzati sugli Emulatori Intellivision per Computer, quindi possono anche non essere perfettamente compatibili con la console Intellivision e RTO.

Suggerimento : Per il trasferimento dei Titoli sulla micro SD è preferibile tenere sul PC una cartella con tutti i Programmi/Giochi e selezionare tutti i Titoli e Cartelle, poi fare click con il tasto destro sul primo Titolo o Cartella in ordine alfa-numerico e selezionare “copia”, poi posizionarsi sulla scheda micro SD e selezionare “incolla” per iniziare il trasferimento.
Questa procedura fa in modo di trasferire tutte le cartelle copiandole in ordine alfabetico/numerico, in modo da trovarle nello stesso ordine sul display OLED della cartuccia RTO.
Allo stesso modo quando volete aggiungere uno o più Programmi/Giochi, la procedura migliore è copiarli nella cartella del PC che contiene quelli già trasferiti precedentemente, poi pulire, ovvero cancellare tutto il contenuto della scheda micro SD e trasferire tutto il contenuto dalla cartella dal PC nella scheda micro SD come descritto precedentemente. In questo modo si evita di trovarsi con gli ultimi titoli aggiunti in testa alla lista, oppure in mezzo a quelli già esistenti, mantenendo così l’ordine alfa/numerico sul display OLED della RTO.
Può succedere che aggiungendo Titoli sulla micro SD che ne contiene già altri, questi ultimi aggiunti vengano mostrati per primi sul display OLED dalla RTO.
Ovviamente nulla vieta di aggiungere i titoli progressivamente e procedere come meglio si preferisce.

COME NOMINARE I FILES

La cartuccia RTO gestisce i nomi lunghi, ma onde evitare il mancato riconoscimento di un titolo è fortemente raccomandabile semplificare il più possibile i titoli, ad esempio evitando lo “Spazio” tra i nomi, ed al suo posto invece utilizzare il segno “Meno - ” e “Underscore _ “, questi simboli sono pienamente supportati dalla cartuccia RTO. Evitare di inserire simboli come il “Punto”, “Apostrofo”, “Virgola”, “Punto Esclamativo/Interrogativo”, “Asterischi”, “Cancelletti” etc. etc. e tenere il nome del file il più corto possibile; sono supportati nomi lunghi fino a 45 caratteri.

Esempio : un titolo come “Masters of the Universe-The Power of He-Man! (1983) (Mattel).bin” conviene ridurlo come segue “Masters_o_t_Universe-T_P_o_He-Man-(1983).bin”; è stato rimosso il punto esclamativo, poi semplificato e accorciato, ma rimane comunque interpretabile, soprattutto per gli appassionati della console Intellivision i quali conoscono benissimo tutti i titoli prodotti.
Si può comunque lasciare invariato il titolo originale senza alcuna semplificazione, a propria scelta, sempre rispettando il numero massimo di 45 caratteri
Solo nel caso in cui, a causa di qualche carattere non supportato, o combinazione di caratteri non graditi, il titolo non compaia sul display OLED della cartuccia RTO (in questo caso compare uno spazio vuoto durante lo scorrimento in avanti e indietro dei titoli) allora si può decidere di semplificare il titolo in oggetto.

Una volta completata la preparazione della scheda micro SD potete inserirla nello slot che si trova sul lato sinistro della RTO; la micro SD deve essere inserita con l’etichetta rivolta verso l’alto, ed i contatti elettrici rivolti verso il basso.
Ora potete inserire la cartuccia RTO nell’alloggiamento cartucce di destra della console Intellivision e quindi accendere il TV o Monitor e la console.

DESCRIZIONE DELLA FUNZIONE DEI PULSANTI DELLA CARTUCCIA RTO

La cartuccia RTO ha tre pulsanti con cui operare ed eseguire le varie funzioni, lo schema seguente mostra la posizione e la denominazione dei pulsanti :

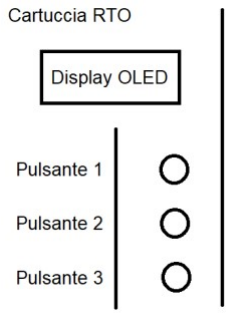
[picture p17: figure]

Funzione dei tre pulsanti prima di fare partire una Rom nella Console Intellivision

P1 – Scorrimento Titoli e Cartelle in avanti
P2 – Entra/Esce da una Cartella – Fa partire il file selezionato (NOTA : per uscire da una Cartella usare P1 o P3 per visualizzare due punti di uscita con i seguenti caratteri : “ . . Kb:0 ” e premere P2
P3 – Scorrimento Titoli e Cartelle indietro

Funzione dei tre pulsanti mentre sta girando un Programma/Gioco nella Console

P1 – Reset Console Intellivision (NOTA : Premuto P1 lo schermo sul TV/Monitor diventa nero, se si vuole far ripartire il Programma/Gioco che stava girando bisogna premere Reset sulla console Intellivision)
P2 – Non Utilizzato
P3 – Reset Cartuccia RTO

All’accensione del TV/Monitor e della console Intellivision si osserva la seguente condizione :
il TV/Monitor mostra uno schermo nero.
Il Display OLED presenta la seguente scritta : “ Push a Button on RTO “, ma premendo uno qualsiasi dei 3 tasti non succede nulla.

Infatti come prima operazione bisogna premere il tasto Reset della console Intellivision, a questo punto comparirà sul TV/Monitor la schermata principale della cartuccia RTO : “ RTO – Cart Please Select a Game “, e la RTO si attiva.

Ora si passa alla visualizzazione delle informazioni sul display OLED della RTO, e usando i pulsanti P1 e P3 si naviga avanti e indietro nei Titoli e Cartelle, e ci si posiziona sul Titolo desiderato.
Premendo P2 si fa partire un Programma/Gioco oppure si entra in una Cartella.
Il Display OLED mostra il nomefile.bin, mentre il nomefile.cfg non viene visualizzato perché serve solo al sistema e la sua visualizzazione non ha utilità pratica.
Sul display OLED della RTO oltre al nomefile.bin la riga sottostante riporta la dimensione della ROM in Kb.

-) Premendo il pulsante 2 la ROM eviedenziata verrà caricata nella console e fatta partire.
-) Il display OLED mostrerà il seguente messaggio : “Running ROM : nomefile.bin”
-) Il TV/Monitor comunque rimarrà nero senza visualizzare nulla.
-) Per far partire il Programma/Gioco bisogna premere il tasto Reset sulla console Intellivision.

-) A questo punto il controllo passa alla console Intellivision e potete usare tutte le funzioni dei “Gamepads” come se fosse stata inserita la cartuccia originale.

Premendo il pulsante Reset della console Intellivision, il Programma/Gioco ripartirà rimanendo sempre presente e comportandosi come se fosse stata inserita la cartuccia originale.
La stessa cosa avviene premendo il pulsante 1 sulla RTO; questo pulsante, mentre il Programma/Gioco sta girando, ha la medesima funzione del tasto Reset della console Intellivision.

Premendo invece il pulsante 3 della RTO, mentre il Programma/Gioco sta girando, verrà fatto il Reset della RTO e rimosso il Programma/Gioco dalla console Intellivision, sul display OLED comparirà : “Push a button on RTO”, il TV/Monitor diventerà nero non mostrando più nulla e si accenderà il Led Rosso sulla RTO.
A questo punto siamo usciti dal Programma/Gioco ma è necessario fare ancora una operazione per poter caricare un nuovo Programma/Gioco, infatti premendo uno qualsiasi dei 3 tasti non succede nulla, bisogna premere il tasto Reset sulla console Intellivision e così comparirà sul TV/Monitor la schermata iniziale “ RTO – Cart Please Select a Game “.

Possiamo quindi ripetere le operazioni viste in precedenza per caricare un nuovo Programma/Gioco.

FORMATI DEI FILES INTELLIVISION

Esistono alcuni formati dei files estratti dalle cartucce Intellivision, di seguito i tre più importanti, cioè tutte le cartucce di cui è stato fatto il “Dump” si trova in almeno uno di questi tre formati :
“nomefile.BIN” “nomefile.INT” “nomefile.ROM”
1) “nomefile.BIN” è il classico file binario estratto dalle rom contenute nelle cartucce Intellivision, questo tipo di file necessita del file di configurazione “nomefile.CFG” come descritto precedentemente.
2) nomefile.INT anche questo è un file binario esattamente uguale al precedente, cambia solo l’estensione, questo tipo di file necessita del file di configurazione “nomefile.CFG” come descritto precedentemente. Questa tipo di estensione è stata adottata sugli Emulatori Intellivision, che, probabilmente dovendo girare anche su PC con sistema operativo Windows non gradivano conflitti di estensione, infatti l’estensione .BIN, era già in uso su questi O.S., ed utilizzandola avrebbe potuto creare problemi di associazione con altri programmi.
3) nomefile.ROM è il file binario con incluso i dati di configurazione, cioè il contenuto del file “nomefile.CFG”, quindi questo tipo di file non necessita del file di configurazione avendolo già internamente.

Come descritto nelle caratteristiche tecniche della cartuccia RTO, il solo formato supportato è il .BIN, infatti se trasferissimo sulla micro SD dei files con le estensioni .INT e .ROM essi non verrebbero visualizzati sul display OLED, e comunque non verrebbero gestiti.
Vediamo come possiamo gestire questi due formati e renderli compatibili con la cartuccia RTO.

nomefile.INT

Per questo formato la procedura è molto semplice, basta rinominare l’estensione da .INT a .BIN
Esempio : “burgertime.int” rinominando l’estensione diventerà “burgertime.bin”, fatto questo semplice passo lo trattiamo esattamente come un file .BIN.
nomefile.ROM

Come descritto precedentemente questo è un file “Embedded” cioè che include nello stesso file .ROM i due files “nomefile.BIN” e “nomefile.CFG”.
Per poterlo usare sulla cartuccia RTO è necessario scorporare i due files e salvarli separatamente.
Per fare questa operazione utilizziamo un programma che gira su sistema operativo Windows che si chiama “rom2bin.exe”

Il programma in oggetto può essere scaricato dal seguente link : http://spatula-city.org/~im14u2c/intv/ dove si trova il SDK (Software Development Kit) dell’ emulatore Intellivision “jzintv”, il programma, dopo avere decompresso il file scaricato “jzintv-20200712-win32-sdl2.zip”, lo trovate contenuto nella cartella “bin/” .
Questo programma è un convertitore di formato, che appunto converte un file .ROM in due files separati .BIN e .CFG Il suo uso è molto semplice: copiare in una cartella il programma “rom2bin.exe” ed i files che si desidera convertire, poi trascinare con il mouse il file “nomefile.rom” sul file programma “rom2bin.exe”, si otterrà come risultato due files distinti “nomefile.bin” e “nomefile.cfg”.
I due files risultanti sono ora compatibili con la cartuccia RTO.

SE UN FILE PROGRAMMA/GIOCO NON GIRA SU RTO

Possiamo trovarci nella condizione di avere trasferito sulla scheda micro SD un Programma/Gioco che non parte, le cause possono essere diverse, di seguito proviamo a trovare la soluzione.
1) Il nome dei files non sono identici e di conseguenza la RTO non trova il file di configurazione.
Soluzione : rinominare il file .CFG esattamente come il file .BIN
2) I due files .bin e .cfg si trovano in una sotto cartella.
Soluzione : spostare i due files nella radice della scheda micro SD o nella cartella della radice ed eliminare la sotto cartella che li conteneva, essa non ha nessuna utilità.
3) Il file .ROM è stato convertito in modo errato ed i due files .BIN e .CFG sono danneggiati.
Soluzione : ripetere la conversione del file.
4) Anche se il file ha l’estensione .BIN non è un file binario .BIN o addirittura non è un file per Intellivision. Soluzione : il file non è utilizzabile
5) Il file .BIN o il file .CFG è corrotto.
Soluzione : il file non è utilizzabile
6) Il file .CFG è errato o compatibile con gli Emulatori per PC e non con la cartuccia RTO Soluzione : correggere o modificare il file .CFG

CORREZZIONE E MODIFICA DEI FILES .CFG

I file .CFG sono nati principalmente per essere utilizzati con gli Emulatori Intellivision per PC; essi sono necessari per poter fornire le informazioni su come allocare e definire gli spazi di memoria per le ROM e le RAM.
Con l’evolversi degli Emulatori anche i file di configurazione hanno iniziato a modificarsi aggiungendo informazioni al loro interno, utili ad uno specifico Emulatore, per cui oggi esistono diversi tipi di file .CFG per lo stesso Programma/Gioco, ma con contenuti e parametri diversi (Ovviamente tranne i parametri di allocazione memoria che devono essere mantenuti).
Vediamo un esempio pratico di un file .CFG standard e lo stesso con una semplice differenza :
“filename.cfg” Standard | “filename.cfg” Differente
[mapping] | [mapping]
$0000 - $1FFF = $5000 | ECS
| $0000 - $1FFF = $5000

Entrambi i files sono corretti e funzionano, quello standard è compatibile con tutti gli emulatori e sicuramente non darà nessun problema, ma nel secondo possiamo notare l’aggiunta di una informazione “ECS”, la quale informa che il Programma/Gioco necessita di periferiche aggiuntive per poter essere utilizzato.
Probabilmente questo secondo file di configurazione è stato generato per un Emulatore che ha la possibilità di utilizzare questa informazione aggiuntiva, ed e possibile che su altri Emulatori possa creare problemi di compatibilità. La cartuccia RTO riconosce la mappatura di memoria standard, quindi con il file di configurazione contenente l’informazione “ECS” non farà partire il Programma/Gioco, perciò dobbiamo modificarlo in quello standard eliminando la riga che contiene “ECS”
Per comprendere meglio come è composto un file di configurazione utilizziamo il seguente esempio :

“Burgertime.cfg”
[mapping]
$0000 - $1FFF = $5000 ; 8K to $5000 - $6FFF $2000 - $2FFF = $D000 ; 4K to $D000 - $DFFF $3000 - $3FFF = $F000 ; 4K to $F000 - $FFFF

“Burgertime_(Hack).cfg”
[mapping]
$0000 - $1FFF = $5000
[memattr]
$D000 - $DFFF = ROM 16
$F000 - $FFFF = ROM 16
[macro]
p 633a 34 ; Infinite peppers (both players)
p 51f9 34 ; Infinite lives (both players)

Sono due file di configurazione dello stesso gioco “Burgertime”, Il primo file è standard e fornisce le indicazioni di mappatura di memoria, il secondo oltre alla mappatura ha due “Hacks”. Entrambi i files sono compatibili con la RTO, infatti, come descritto precedentemente la RTO può attivare gli “Hacks”, la cosa importante è che prima della riga [mapping] non ci siano altre righe di testo o di parametri, se fossero presenti, il Programma/Gioco non verrebbe eseguito, se riscontrate questa situazione cancellate tutte le righe posizionate prima di [mapping].

Nell’esempio che segue si può vedere un file di configurazione di “Burgertime” piuttosto complesso, che contiene molte informazioni e “Hacks”, questo file non funzionerebbe sulla cartuccia RTO.
Questo file è compatibile con gli Emulatori per Computer, i quali possono gestire molteplici parametri di configurazione e di informazioni.
Per renderlo compatibile con la cartuccia RTO è necessario eliminare tutte le righe riportate in “Corsivo Sottolineate” e quindi iniziare il file con il testo evidenziato in grassetto [mapping]

;;;BurgerTime! (Trainer) (1982) (Mattel) [h].cfg
;;;20210616gernotschrader
[vars]
kc_compat = 0
name = "BurgerTime!, Trainer (128 Cooks)" short_name = "BurgerTime!, Trn."
author = "Data East / Ray Kaestner" publisher = "Mattel Electronics" release_date = 1982
;
[mapping]
$0000 - $1FFF = $5000
;
[memattr]
$9000 - $91FF = ROM 16
;
[macro]
p 500a 0 ; date / title $9000 ($5040) p 500b 90 ; "
p 5013 4 ; border color
;
p 51ce 7f ; reserve Peter & Pepper (4)

Per correggere o modificare un file “nomefile.cfg” utilizzare un PC (le indicazioni che seguono prendono in considerazione un PC con S.O. Windows) con un “Text Editor”, va benissimo il “Notepad”.
Aggiungere temporaneamente l’estensione .TXT al file .CFG, quindi il file “nomefile.cfg” diventerà “nomefile.cfg.txt”, il PC aprirà una finestra ed avvertirà che cambiando l’estensione il file potrebbe diventare inutilizzabile, premere “OK” per accettare la modifica dell’estensione.
Caricare il file con il “Text Editor” e procedere nella modifica del file di configurazione, poi salvare, chiudere il “Text Editor” ed infine cancellare l’estensione .TXT che è stata aggiunta, il vostro file di configurazione è pronto per essere provato.

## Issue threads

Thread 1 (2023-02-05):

Incompatibilità schede micro SD?

repetto74, 2023-02-05:
Ciao

Bellissimo progetto per la Intellivision che aspettavo da tempo :-).
Avendo un Teensy 4.1 nel cassetto mi sono deciso a montare questa RTO. Tutto sembrava funzionare in un primo momento usando i binari TOSEC della Intellivision e abbinando il file .cfg.
Purtroppo dopo una seconda prova, il Teensy non vede piu i binari registrati sulla SD. Sono state segnalate incompatibilità con alcune schede SD? Le ho prese su Ali a poco prezzo dunque non so quanto siano affidabili :-).
Possibilità di avere un HEX corrotto sul Teensy? (possibilità remota penso).
Grazie e complimenti :-)
Rick

aotta, 2023-02-05:
Ciao, no fino ad ora nessun problema segnalato con le sd, anche se
ovviamente non sono state create ancora molte rto, o almeno quelle di cui
ho notizia. Ti consiglio di flashare la teensy con uno dei programmi di
prova della libreria sd per escludere problemi con quella.
Ma hai per caso flashato la versione 1.1a? Nella versione beta all'avvio
non legge subito la scheda.
Buona fortuna con le prove e saluti
Andrea

Il dom 5 feb 2023, 18:50 repetto74 ***@***.***> ha scritto:

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

repetto74, 2023-02-05:
Ciao Andrea :-)
Non so a quale programma ti riferisci. Io ho flashato il Teensy usando il file RTO.ino disponibile nella cartella del progetto. Per fare cio' ho dovuto installare il modulo di gestione delle Teensy su Arduino IDE (piu alcune librerie mancanti) e flashare da l'IDE. Ha funzionato al primo colpo ma poi ha deciso di non farmi più vedere i .bin presenti nella SD.

aotta, 2023-02-05:
Intendo i programmi che dovresti trovare dall'IDE in File/esempi/SD, sono
programmi che leggono le info della SDCard e la testano in scrittura e
lettura.
Se quelli funzionano, non è un problema della SDCard.
Puoi anche provare sempre da IDE arduino a lanciare il "monitor seriale", e
leggere se da qualche messaggio di errore la RTO (anche se dovrebbe darli
sullo schermo oled, cosa che immagino non hai).

Il giorno dom 5 feb 2023 alle ore 19:04 repetto74 ***@***.***>
ha scritto:

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

repetto74, 2023-02-05:
No nessun messaggio di errore sullo schermo OLED. Ho creato una cartella per gioco dove inserire il .bin e .cfg. Posso navigare tranquillamente nelle varie cartelle ma risultano tutte vuote.

repetto74, 2023-02-06:
Ciao :-). Ho provato con una micro SD di buona marca e tutto ok. Dunque le micro SD scadenti possono dare problemi in lettura.
Grazie per questa bella scheda ;-)
Riccardo

aotta, 2023-02-06:
Benissimo, chiudo la issue, che comunque è legata al lettore integrato nella Teensy 4.1, non al progetto RTO.

Closed 2023-02-06.

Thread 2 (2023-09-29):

BOM

pmgducati, 2023-09-29:
Can you post a Bill of Materials?

pmgducati, 2023-09-29:
I installed KiCAD and found all the component Values.  The only thing that I am missing is the OLED screen.  Can you provide a source for that?

aotta, 2023-09-29:
You can simply search for "oled 128x32 i2c display” on popular web markets

Il ven 29 set 2023, 22:15 pmgducati ***@***.***> ha scritto:

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

pmgducati, 2023-09-29:
Perfect, thanks!

Closed 2023-09-29.

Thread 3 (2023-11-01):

Workaround reset issue

JaneDoe649, 2023-11-01:
Hello aotta,

Thank you for your work on this project. As with many, resetting the console via the cartridge works poorly. Browsing through 5-11under's posts on the Atariage forum, I found a software solution that works for me and requires no hardware modification.

Rather than setting buffer 245 to high impedance, I switch it to input to let the reset circuit capacitor charge.

Here are the changes.

New macros are defined:

`#define resetLow() digitalWriteFast(DIR2_PIN,HIGH); pinMode(RST_PIN,OUTPUT); digitalWriteFast(RST_PIN,LOW); // A->B, TEENSY to INTV BUS ; RST Output set to 0`
`#define resetHigh() pinMode(RST_PIN,INPUT); digitalWriteFast(DIR2_PIN,LOW); // RST is INPUT; B->A, INTV BUS to TEENSY`

Lines 615 and 618:

`pinMode(RST_PIN,OUTPUT);`
`digitalWriteFast(RST_PIN,LOW);   //???????????`

are replaced by this single line:

`resetHigh();`

reset function is replaced by 5-11under's adapted function :

```// https://forums.atariage.com/topic/346024-intellivision-rto-multicart-new-multicart/page/5/

void resetCart() {
  //digitalWriteFast(RST_PIN,HIGH);
  resetHigh();
  digitalWriteFast(Status_PIN,HIGH);
  delay(30);  // was 20 for Model II; 30 works for both

  //digitalWriteFast(RST_PIN,LOW);
  resetLow();
  delay(3);  // was 2 for Model II; 3 works for both
  while (digitalReadFast(MSYNC_PIN)==1) {};

  delay(1);  // was 1 for Model II
  //digitalWriteFast(RST_PIN,HIGH);
  resetHigh();
  digitalWriteFast(Status_PIN,LOW);
}

aotta, 2023-11-01:
Really interesting, I'm pretty sure it's not an hw issue but both my intellivision I have new caps and reset each time with no issue, so i can't make any further test. And, i don't have an Inty II to try. Since, if I'm not wrong, you tested your patch with both kind of console, your workaround is a good candidate for committing original code. I'll ask to some friends with poor reset to give a try to your code, but of course feedback from anyone are welcome!

JaneDoe649, 2023-11-01:
I was only able to test it on an Intellivision 1 with its original capacitor.

References to model II in the function come from tests carried out by 5-11under, which inspired me.

https://forums.atariage.com/topic/346024-intellivision-rto-multicart-new-multicart/page/5/

Tissemon, 2023-11-01:
Thanks for this fix, but unfortunately it didn't work for me. I've got a fully recapped PAL INTV1 where the RTO only starts after I press reset (I've even tested with multiple different RTO-carts). With this fix it sometimes boots to the RTO-logo, but most of the time I have to press reset to get it. After I select a game I always have to press reset.
Let me know if you've got any other idea - I'm happy to test any software-solution to this "problem".

Closed 2024-02-09.

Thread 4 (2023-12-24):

Screw for Cart housing

pmgducati, 2023-12-24:
Hello,
What size screw should I use for the shell?  I used the models provided in the repo.

Thanks!

aotta, 2023-12-24:
Hi, i used M2,5 20mm self-tapping screws with flat head.

Closed 2024-02-09.

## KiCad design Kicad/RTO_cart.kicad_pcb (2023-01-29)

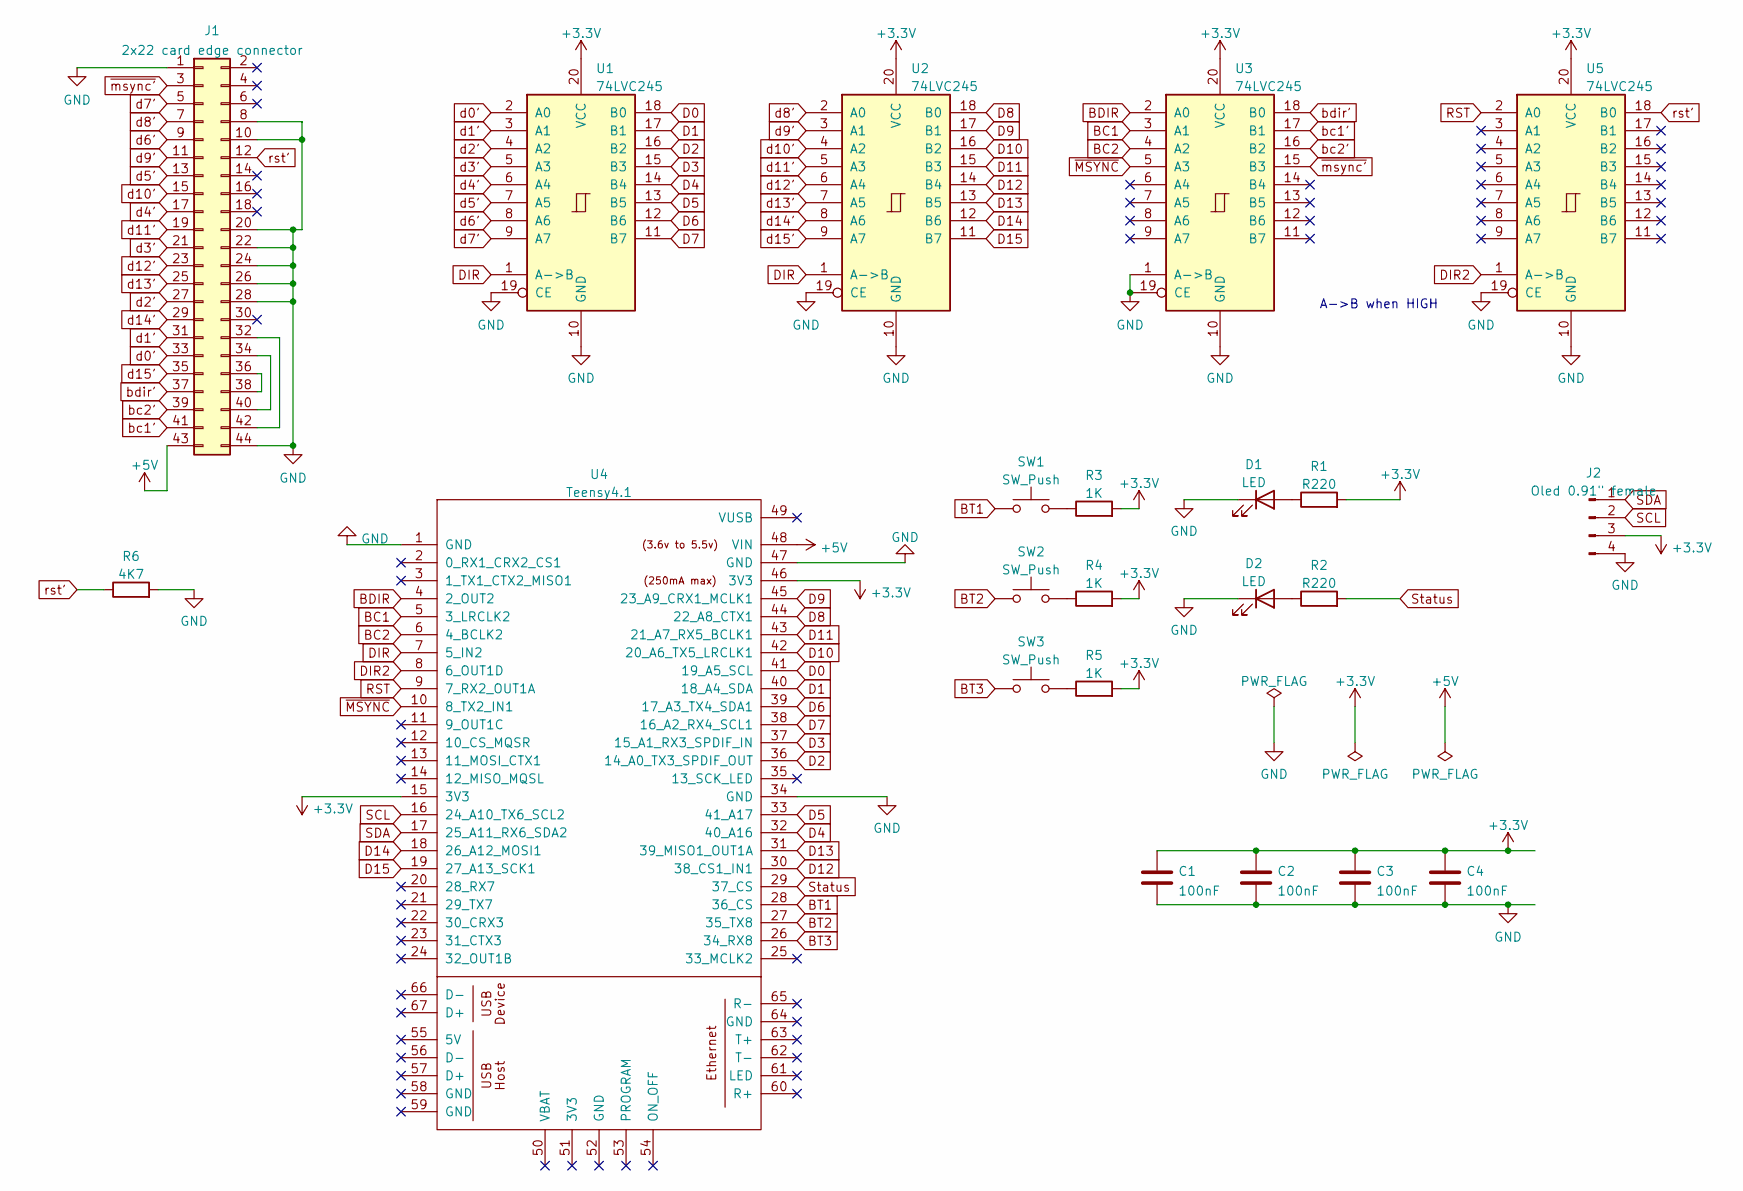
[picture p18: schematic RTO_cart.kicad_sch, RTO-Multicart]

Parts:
C1, C2, C3, C4: 100nF; C_Disc_D3.8mm_W2.6mm_P2.50mm
D1, D2: LED; LED_D3.0mm
J1: 2x22 card edge connector; edge mounted 44 pin card edge connector (2x22 pin)
J2: Oled 0.91" female; PinHeader_1x04_P2.54mm_Vertical
R1, R2: R220; R_Axial_DIN0204_L3.6mm_D1.6mm_P7.62mm_Horizontal
R3, R4, R5: 1K; R_Axial_DIN0204_L3.6mm_D1.6mm_P7.62mm_Horizontal
R6: 4K7; R_Axial_DIN0204_L3.6mm_D1.6mm_P7.62mm_Horizontal
SW1, SW2, SW3: SW_Push; SW_PUSH_6mm
U1, U2, U3, U5: 74LVC245; DIP-20_W7.62mm_Socket
U4: Teensy4.1; Teensy41

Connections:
+3.3V: C1.1, C2.1, C3.1, C4.1, J2.3, R1.2, R3.2, R4.2, R5.2, U1.20 (VCC), U2.20 (VCC), U3.20 (VCC), U4.15 (3V3), U4.46 (3V3), U5.20 (VCC)
+5V: J1.43, U4.48 (VIN)
BC1: U3.3 (A1), U4.5 (3_LRCLK2)
BC2: U3.4 (A2), U4.6 (4_BCLK2)
BDIR: U3.2 (A0), U4.4 (2_OUT2)
BT1: SW1.1, U4.28 (36_CS)
BT2: SW2.1, U4.27 (35_TX8)
BT3: SW3.1, U4.26 (34_RX8)
D0: U1.18 (B0), U4.41 (19_A5_SCL)
D1: U1.17 (B1), U4.40 (18_A4_SDA)
D2: U1.16 (B2), U4.36 (14_A0_TX3_SPDIF_OUT)
D3: U1.15 (B3), U4.37 (15_A1_RX3_SPDIF_IN)
D4: U1.14 (B4), U4.32 (40_A16)
D5: U1.13 (B5), U4.33 (41_A17)
D6: U1.12 (B6), U4.39 (17_A3_TX4_SDA1)
D7: U1.11 (B7), U4.38 (16_A2_RX4_SCL1)
D8: U2.18 (B0), U4.44 (22_A8_CTX1)
D9: U2.17 (B1), U4.45 (23_A9_CRX1_MCLK1)
D10: U2.16 (B2), U4.42 (20_A6_TX5_LRCLK1)
D11: U2.15 (B3), U4.43 (21_A7_RX5_BCLK1)
D12: U2.14 (B4), U4.30 (38_CS1_IN1)
D13: U2.13 (B5), U4.31 (39_MISO1_OUT1A)
D14: U2.12 (B6), U4.18 (26_A12_MOSI1)
D15: U2.11 (B7), U4.19 (27_A13_SCK1)
DIR: U1.1 (A->B), U2.1 (A->B), U4.7 (5_IN2)
DIR2: U4.8 (6_OUT1D), U5.1 (A->B)
GND: C1.2, C2.2, C3.2, C4.2, D1.1 (K), D2.1 (K), J1.1, J1.8, J1.10, J1.20, J1.22, J1.24, J1.26, J1.28, J1.44, J2.4, R6.2, U1.10 (GND), U1.19 (CE), U2.10 (GND), U2.19 (CE), U3.1 (A->B), U3.10 (GND), U3.19 (CE), U4.1 (GND), U4.34 (GND), U4.47 (GND), U5.10 (GND), U5.19 (CE)
unnamed: D1.2 (A), R1.1
unnamed: D2.2 (A), R2.1
unnamed: J1.32, J1.42
unnamed: J1.34, J1.40
unnamed: J1.36, J1.38
unnamed: R3.1, SW1.2
unnamed: R4.1, SW2.2
unnamed: R5.1, SW3.2
RST: U4.9 (7_RX2_OUT1A), U5.2 (A0)
SCL: J2.2, U4.16 (24_A10_TX6_SCL2)
SDA: J2.1, U4.17 (25_A11_RX6_SDA2)
Status: R2.2, U4.29 (37_CS)
bc1': J1.41, U3.17 (B1)
bc2': J1.39, U3.16 (B2)
bdir': J1.37, U3.18 (B0)
d0': J1.33, U1.2 (A0)
d1': J1.31, U1.3 (A1)
d2': J1.27, U1.4 (A2)
d3': J1.21, U1.5 (A3)
d4': J1.17, U1.6 (A4)
d5': J1.13, U1.7 (A5)
d6': J1.9, U1.8 (A6)
d7': J1.5, U1.9 (A7)
d8': J1.7, U2.2 (A0)
d9': J1.11, U2.3 (A1)
d10': J1.15, U2.4 (A2)
d11': J1.19, U2.5 (A3)
d12': J1.23, U2.6 (A4)
d13': J1.25, U2.7 (A5)
d14': J1.29, U2.8 (A6)
d15': J1.35, U2.9 (A7)
rst': J1.12, R6.1, U5.18 (B0)
~MSYNC: U3.5 (A3), U4.10 (8_TX2_IN1)
~msync': J1.3, U3.15 (B3)

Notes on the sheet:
A->B when HIGH

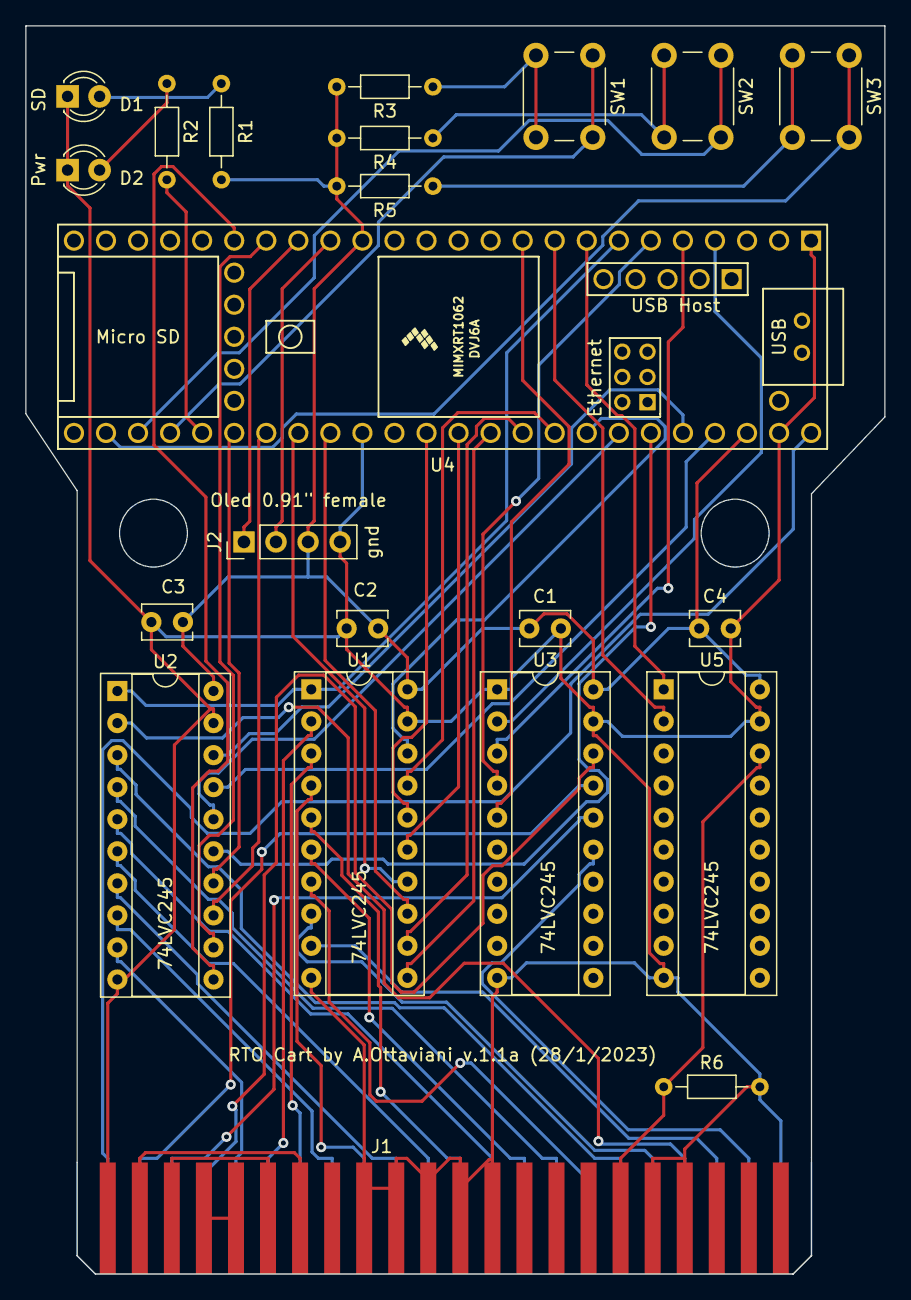
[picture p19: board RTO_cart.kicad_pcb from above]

Board: 2 copper layers, 68.1 x 98.9 mm, 22 parts (0 on the bottom side), 61 nets.

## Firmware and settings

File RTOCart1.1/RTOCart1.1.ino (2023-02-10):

/*
//                       RTO-CART by Andrea Ottaviani 
// Intellivision multicart based on Teensy 4.1 board -
// v. 1.1 2023-01-24 : added reset handling
//                     fixed pin 8 video bug (connected to GND)
//                     added third button for prev file
//                     to do: check for extmem for dimensioning ROM size buffer
// v. 0.1 2022-11-11 : Initial version
//
// Thanks to John Dullea (dwarfaxe@yahoo.com) for his support and his ACC projects, from wich i get some bits of code
// 
//  More info on https://github.com/aotta/RTO-Cart
*/

// include for Oled display
#include <SPI.h>
#include <Wire.h>               // SCL pin 19, SDA pin 18 SCL2 25, SDA2 24

#include <Adafruit_GFX.h>      
#include <Adafruit_SSD1306.h>   

#define SCREEN_WIDTH 128 // OLED display width, in pixels
#define SCREEN_HEIGHT 32 // OLED display height, in pixels

// Declaration for an SSD1306 display connected to I2C (SDA, SCL pins)
// The pins for I2C are defined by the Wire-library. 
// On an arduino UNO:       A4(SDA), A5(SCL)
// On an arduino MEGA 2560: 20(SDA), 21(SCL)
// On an arduino LEONARDO:   2(SDA),  3(SCL), ...
#define OLED_RESET     -1 // Reset pin # (or -1 if sharing Arduino reset pin)
#define SCREEN_ADDRESS 0x3C ///< See datasheet for Address; 0x3D for 128x64, 0x3C for 128x32
Adafruit_SSD1306 display(SCREEN_WIDTH, SCREEN_HEIGHT, &Wire2, OLED_RESET);

 // include the SD library:
//-#include <SD.h>

#include "splash.h"
#include <FS.h>
#include <SdFat.h>

// SDCARD_SS_PIN is defined for the built-in SD on some boards.
#ifndef SDCARD_SS_PIN
const uint8_t SD_CS_PIN = SS;
#else  // SDCARD_SS_PIN
// Assume built-in SD is used.
const uint8_t SD_CS_PIN = SDCARD_SS_PIN;
#endif  // SDCARD_SS_PIN


// change this to match your SD shield or module;
// Teensy 3.5 & 3.6 & 4.1 on-board: BUILTIN_SDCARD
//const int chipSelect = BUILTIN_SDCARD;


// Try max SPI clock for an SD. Reduce SPI_CLOCK if errors occur.
#define SPI_CLOCK SD_SCK_MHZ(50)

// Try to select the best SD card configuration.
#if HAS_SDIO_CLASS
#define SD_CONFIG SdioConfig(FIFO_SDIO)
#elif  ENABLE_DEDICATED_SPI
#define SD_CONFIG SdSpiConfig(SD_CS_PIN, DEDICATED_SPI, SPI_CLOCK)
#else  // HAS_SDIO_CLASS
#define SD_CONFIG SdSpiConfig(SD_CS_PIN, SHARED_SPI, SPI_CLOCK)
#endif  // HAS_SDIO_CLASS

// set up variables using the SD utility library functions:
SdFs sd;
FsFile root;
FsFile entry;
FsFile mapfile;
//-File root;
//-File entry;
//-File mapfile;

// here is one continuous block of 16 bits
// should be able to read like this
// uint16_t addr= (GPIO6_DR & 0xFF00) / 256;

// Teensy pin usage definitions
#define D0_PIN    19 //GPIO6_16
#define D1_PIN    18 //GPIO6_17
#define D2_PIN    14 //GPIO6_18
#define D3_PIN    15 //GPIO6_19
#define D4_PIN    40 //GPIO6_20
#define D5_PIN    41 //GPIO6_21
#define D6_PIN    17 //GPIO6_22
#define D7_PIN    16 //GPIO6_23
#define D8_PIN    22 //GPIO6_24
#define D9_PIN    23 //GPIO6_25
#define D10_PIN   20 //GPIO6_26
#define D11_PIN   21 //GPIO6_27
#define D12_PIN   38 //GPIO6_28
#define D13_PIN   39 //GPIO6_29
#define D14_PIN   26 //GPIO6_30
#define D15_PIN   27 //GPIO6_31

int D_PIN[] ={19,18,14,15,40,41,17,16,22,23,20,21,38,39,26,27};

#define BDIR_PIN  2 //GPIO4_4
#define BC1_PIN   3 //GPIO4_5
#define BC2_PIN   4 //GPIO4_6
#define DIR_PIN   5 //GPIO4_8 - TO PIN 1 LVC245, HIGH= A->B (INPUT 5V TO 3.3V) LOW= B->A (OUTPUT 3.3V TO 5V)
#define DIR2_PIN  6 //GPIO2_10 - TO PIN 1 LVC245, HIGH= A->B (INPUT 5V TO 3.3V) LOW= B->A (OUTPUT 3.3V TO 5V)
#define BT2_PIN  35 //GPIO2_26
#define BT1_PIN  36 //GPIO2_28
#define BT3_PIN  34 //GPIO2_29
#define Status_PIN   37 //GPIO2_19
#define RST_PIN   7 //GPIO2_17
#define MSYNC_PIN   8 //GPIO2_16

// Inty bus values (BC2+BC1+BDIR)
#define BUS_NACT  0b000  //0
#define BUS_ADAR  0b010  //2
#define BUS_IAB   0b100  //4
#define BUS_DTB   0b110  //6
#define BUS_BAR   0b001  //1
#define BUS_DW    0b011  //3
#define BUS_DWS   0b101  //5
#define BUS_INTAK 0b111  //7

unsigned char busLookup[8];

#define BUS_STATE_MASK  0x00000070L // gpio9_4.5.6 pins 5.6.7
#define BUS_DIR_MASK 0x00000100L // gpio9_8 pin 9 


char RBLo,RBHi;
#define BINLENGTH  224000L
#define RAMSIZE  8192
//EXTMEM unsigned int ROM[BINLENGTH];
uint16_t ROM[BINLENGTH] DMAMEM;
uint16_t RAM[RAMSIZE] DMAMEM;
#define maxHacks 32
uint16_t HACK[maxHacks];
uint16_t HACK_CODE[maxHacks];

unsigned int romLen;

unsigned int ramfrom = 0;
unsigned int ramto =   0;
unsigned int mapfrom[80];
unsigned int mapto[80];
unsigned int maprom[80];
unsigned int addrto[80];
unsigned int RAMused = 0;

unsigned int tipo[80];  // 0-rom / 1-page / 2-ram
unsigned int page[80];  // page number
int slot;
int hacks;

uint32_t selectedfile_size;       // BIN file size
char longfilename[46];        // long file name (trunked) 
char mapfilename[46];          // map cfg file name
int lenfilename; 
char path[50];

/////////////////////////////////////////////////////////////////////
//                   SelectBinFile()                               //
/////////////////////////////////////////////////////////////////////


void SelectBinFile() // adapted from my SDLEP-TFT project  http://dcmoto.free.fr/   
{
  int i; 
  int rootpos[255];
  int curpos=0;
  int lastpos;
 
  char suf[10];                 // extension file 
  uint64_t file_size;        // tailles des fichiers affiches
  // Initialisations
  selectedfile_size = 0;          // initialisation de la taille du fichier choisi
  file_size = 0;
  bool selected = false;
  bool filefound = false;
  int subfolder = 0;    // nexting subfolders counter
  int dot = 0;
 
      display.clearDisplay();
      display.setTextSize(1);
      display.setTextColor(1);
      display.setCursor(0, 1);
      display.print("Reading card..");
      display.display();
      //delay(1000);
    
    // Boucle de choix du fichier
   path[0]=0;
   if (!(root=sd.open("/"))) {
    Serial.println("Error opening Root");
   }
   // wait all buttons are released
  while(digitalReadFast(BT1_PIN)|digitalReadFast(BT2_PIN)|digitalReadFast(BT3_PIN)) 
  while (!selected)
  {
     while (!filefound) 
    {
        //read next file
        lastpos=root.curPosition();
        entry=root.openNextFile();
 
      if(!entry)
      {
        if (subfolder>0) {
          strcpy(longfilename,"..");
        root.rewindDirectory();
         break; 
        } else {
        root.rewindDirectory();
        lastpos=root.curPosition();
        entry=root.openNextFile();
        entry.getName(longfilename,45);
        break;
        }
      //entry.close();
        continue;      
      }

        if(entry.isDirectory()) {   //handling subdirectory
          entry.getName(longfilename,45);
          if (strcmp(longfilename,"System Volume Information")==0) {
           continue;
         } else {
           filefound=true;
           break; 
         }
        }

      for(i=0; i<46; i++) longfilename[i]=0; 
      entry.getName(longfilename,45);
      dot=0;
      for(i=0; i<43; i++) {
        if (longfilename[i]=='.') {
          dot=i;
        }
      }    
      if(dot==0) 
      {
        continue; //dot not found, get next file
      }
      suf[0]=0;
      //test du suffixe
      suf[0]=longfilename[dot+1];
      suf[1]=longfilename[dot+2];
      suf[2]=longfilename[dot+3];
      suf[3]=0;
    
      if(strcmp(suf,"bin")!=0  && strcmp(suf,"BIN")!=0 )
        continue; //not BIN file
      filefound=true;
    }

     // .bin found
     // save position
        rootpos[curpos]=lastpos;
        curpos++;
     
      file_size = entry.size();
      int kb=(file_size >>10);
      display.clearDisplay();
      display.setTextSize(1);
      display.setTextColor(1);
      display.setCursor(0, 1);
      display.print(longfilename);
      display.setCursor(0,24);
      if (entry.isDirectory()) {
        display.print("DIR");
      } else 
      { display.print("KB:");
      display.setCursor(22,24);
      display.print(kb,DEC);
      }
      display.display();
    
    filefound=false;
    
    
    //check user button and time
    while (1)
    {
      //Next button
      if (digitalRead(BT1_PIN)) {
          digitalWriteFast(Status_PIN,HIGH);
          delay(300);
          digitalWriteFast(Status_PIN,LOW);
          break; // readnext file
       }

      //Prev button
      if (digitalRead(BT3_PIN)) {
          digitalWriteFast(Status_PIN,HIGH);
          delay(300);
          digitalWriteFast(Status_PIN,LOW);
          if (curpos>1) {
            curpos-=2;
          } else {
            curpos=0;
          }
          root.seekSet(rootpos[curpos]);
          break;
      }
      //SELECT Button
      if (digitalRead(BT2_PIN)) {
          digitalWriteFast(Status_PIN,HIGH);
          delay(300);
          digitalWriteFast(Status_PIN,LOW);
          if (entry.isDirectory()) {
            root=sd.open(longfilename);
            strcat(path,longfilename);
            subfolder++;
            break;
          } else 
          if (strcmp(longfilename,"..")==0) {
            root=sd.open("/");
            for(i=0;i<50;i++) path[i]=0;
            subfolder--;
            break;
          } else {
          selected=true;
          break; // readnext file
          }
        }
      } 
    } //fin de la boucle de choix du fichier (on en sort si le fichier a ete choisi)
  //root.close();  //fermeture du repertoire de la carte SD
  //return file_return;
}

////////////////////////////////////////////////////////////////////////////////////
//                     LOAD ROM
////////////////////////////////////////////////////////////////////////////////////

void loadROM() {

  
  String riga;
  char tmphex[] {0,0,0,0,0,0};
  int linepos;

 
  for(int i=0; i<45; i++) {
        if (longfilename[i]=='.') {
          lenfilename= i;  //dot found
        }
  }
  
  memcpy(mapfilename,longfilename,lenfilename);
  strcat(mapfilename,".cfg");
 
  strcat(path,"/");
  strcat(path,mapfilename);
  mapfile=sd.open(path);
  //  mapfile=SD.open(mapfilename);
  if (!mapfile) {
    mapfile.openNextFile();
    mapfile=sd.open("0.cfg");
    }
  if (!mapfile) {
    display.clearDisplay();
    display.setCursor(0, 1);
    display.print("Map CFG file error");
    display.setCursor(0,16);
    display.print("restart RTO");
    display.display();
    while(1);
  }

  slot=0;
  hacks=0;
  
  while (mapfile.available()) {
    riga=mapfile.readStringUntil('\n');
    if (riga.length()>1) {
      String tmp=riga.substring(0,9);
      if (slot==0) {
        if (tmp=="[mapping]") {
          riga=mapfile.readStringUntil('\n');
        } else {
          display.clearDisplay();
          display.setCursor(0, 1);
          display.print("[mapping] not found");
          display.display();
          while(1);
        }
      }
    
      if (tmp=="[memattr]") {
        riga=mapfile.readStringUntil('\n');
        Serial.println("Memattr");
        tmp=riga.substring(1,5);
        tmp.toCharArray(tmphex,5);
        ramfrom=strtoul(tmphex,NULL,16);
        mapfrom[slot]=ramfrom;
        tmp=riga.substring(9,13);
        tmp.toCharArray(tmphex,5);
        ramto=strtoul(tmphex,NULL,16);
        mapto[slot]=ramto;
        maprom[slot]=ramfrom;
        addrto[slot]=maprom[slot]+(mapto[slot]-mapfrom[slot]);
        tipo[slot]=2; // RAM
        RAMused=1;
        slot++;
      } else {
        tmp=riga.substring(0,1);
        if (tmp=="p") {
          // [MACRO]
          tmp=riga.substring(2,6);
          tmp.toCharArray(tmphex,6);
          HACK[hacks]=strtoul(tmphex,NULL,16);
          tmp=riga.substring(7,10);
          tmp.toCharArray(tmphex,4);
          HACK_CODE[hacks]=strtoul(tmphex,NULL,16);
          Serial.print(HACK[hacks],HEX);Serial.print("-");
          Serial.println(HACK_CODE[hacks],HEX);
          hacks++;
        } else {
        //mapping
        linepos=riga.indexOf("-");
        if (linepos>=0) {
          tmp=riga.substring(1,linepos-1);
          tmp.toCharArray(tmphex,6);
          mapfrom[slot]=strtoul(tmphex,NULL,16);
          tmp=riga.substring(linepos+3,linepos+9);
          tmp.toCharArray(tmphex,6);
          mapto[slot]=strtoul(tmphex,NULL,16);
          if (linepos==6) {
            tmp=riga.substring(linepos+11,linepos+15);
          } else {
            tmp=riga.substring(linepos+12,linepos+17);
          }
          tmp.toCharArray(tmphex,6);
          maprom[slot]=strtoul(tmphex,NULL,16);
          if (linepos==6) {
            tmp=riga.substring(22,26);
          } else {
            tmp=riga.substring(24,28);
          }  
          tmp.toCharArray(tmphex,6);
          addrto[slot]=maprom[slot]+(mapto[slot]-mapfrom[slot]);
          if (!(strcmp(tmphex,"PAGE"))) {
            tipo[slot]=1;
            if (linepos==6) {
              tmp=riga.substring(27,28);
            } else {
              tmp=riga.substring(29,31);
            }   
          tmp.toCharArray(tmphex,2);
          page[slot]=strtoul(tmphex,NULL,16);
          } else {
            tipo[slot]=0;
          }
          slot++;
          }
        }
        Serial.print("Slot:");Serial.print(slot-1);
        Serial.print("-From:");Serial.print(mapfrom[slot-1],HEX);
        Serial.print(" to:");Serial.print(mapto[slot-1],HEX);
        Serial.print(" IN:");Serial.print(maprom[slot-1],HEX);
        Serial.print(" tipo:");Serial.print(tipo[slot-1]);
        Serial.print(" page:");Serial.print(page[slot-1]);
        Serial.print(" addr-to:");Serial.println(addrto[slot-1],HEX);
        }
     }
  }
     
  slot--;  // conservo il numero di slot!
  Serial.print("Slots:");Serial.println(slot);
  if (entry) {
    // read from the file until there's nothing else in it:
    romLen=0;
    while (entry.available()) {
      RBHi = entry.read();
      RBLo = entry.read();
      unsigned int dataW= RBLo | (RBHi << 8);
      //fileOffset=romLen - mapfrom[slot] + maprom[slot];
      ROM[romLen]=dataW;
      romLen++;
         if (romLen>BINLENGTH) {
          display.clearDisplay();
          display.setCursor(0, 1);
          display.print("File too big!");
          display.setCursor(0,16);
          display.print(longfilename);
          display.display();
          while(1);
      }
  
    }
    //verify
  //  slot=0;
    romLen=0;
    entry.seek(0);
    while (entry.available()) {
      RBHi=entry.read();
      RBLo=entry.read();
      unsigned int dataW= RBLo | (RBHi << 8);
      //fileOffset=romLen - mapfrom[slot] + maprom[slot];
      if (ROM[romLen]!= dataW) {
        display.clearDisplay();
        display.setCursor(0, 1);
        display.print("Verify file error!");
        display.display();
        while(1);
      } 
      romLen++;
     } 
    // close the file:
    entry.close();
  } else {
    // if the file didn't open, print an error:
    display.clearDisplay();
    display.setCursor(0, 1);
    display.print("Error opening file:");
    display.setCursor(0,16);
    display.print(longfilename);
    display.display();
    return; 
     }
  if (hacks>0) {
    display.clearDisplay();
    display.setCursor(0, 1);
    display.print("Hack found: use it?");
    display.setCursor(0,16);
    display.print("OK to confirm, Next or Prev to deny");
    display.display();
    delay(500); // wait to clear buttons
    while(((digitalReadFast(BT1_PIN)==0) & (digitalReadFast(BT2_PIN)==0) & (digitalReadFast(BT3_PIN)==0))) {
      if ((digitalReadFast(BT1_PIN)==1) | (digitalReadFast(BT3_PIN)==1)) hacks=0;
    }
  } 
}

////////////////////////////////////////////////////////////////////////////////////
//                     SETUP
////////////////////////////////////////////////////////////////////////////////////
void setup() {

  long MUX = 21;
  IOMUXC_SW_MUX_CTL_PAD_GPIO_AD_B1_00 = MUX;  
  IOMUXC_SW_MUX_CTL_PAD_GPIO_AD_B1_01 = MUX;
  IOMUXC_SW_MUX_CTL_PAD_GPIO_AD_B1_02 = MUX;
  IOMUXC_SW_MUX_CTL_PAD_GPIO_AD_B1_03 = MUX;
  IOMUXC_SW_MUX_CTL_PAD_GPIO_AD_B1_04 = MUX;
  IOMUXC_SW_MUX_CTL_PAD_GPIO_AD_B1_05 = MUX;
  IOMUXC_SW_MUX_CTL_PAD_GPIO_AD_B1_06 = MUX;
  IOMUXC_SW_MUX_CTL_PAD_GPIO_AD_B1_07 = MUX;
  IOMUXC_SW_MUX_CTL_PAD_GPIO_AD_B1_08 = MUX;
  IOMUXC_SW_MUX_CTL_PAD_GPIO_AD_B1_09 = MUX;
  IOMUXC_SW_MUX_CTL_PAD_GPIO_AD_B1_10 = MUX;
  IOMUXC_SW_MUX_CTL_PAD_GPIO_AD_B1_11 = MUX;
  IOMUXC_SW_MUX_CTL_PAD_GPIO_AD_B1_12 = MUX;
  IOMUXC_SW_MUX_CTL_PAD_GPIO_AD_B1_13 = MUX;
  IOMUXC_SW_MUX_CTL_PAD_GPIO_AD_B1_14 = MUX;
  IOMUXC_SW_MUX_CTL_PAD_GPIO_AD_B1_15 = MUX;

  IOMUXC_SW_MUX_CTL_PAD_GPIO_EMC_04 = MUX; //GPIO4_4  BDIR
  IOMUXC_SW_MUX_CTL_PAD_GPIO_EMC_05 = MUX; //GPIO4_5  BC1
  IOMUXC_SW_MUX_CTL_PAD_GPIO_EMC_06 = MUX; //GPIO4_6  BC2

  long PAD = 0B00000000000000010011000000111000;
  //           |||||||||||||||||||||||||||||||+-FAST
  //           |||||||||||||||||||||||||||||++--RESERVED
  //           ||||||||||||||||||||||||||+++----DSE
  //           ||||||||||||||||||||||||++-------SPEED 
  //           |||||||||||||||||||||+++---------RESERVED
  //           ||||||||||||||||||||+------------ODE (OPEN DRAIN) 
  //           |||||||||||||||||||+-------------PKE
  //           ||||||||||||||||||+--------------PUE
  //           ||||||||||||||||++---------------PUS
  //           |||||||||||||||+-----------------HYS
  //           ++++++++++++++++-----------------RESERVED
  IOMUXC_SW_PAD_CTL_PAD_GPIO_AD_B1_00 = PAD;
  IOMUXC_SW_PAD_CTL_PAD_GPIO_AD_B1_01 = PAD;
  IOMUXC_SW_PAD_CTL_PAD_GPIO_AD_B1_02 = PAD;
  IOMUXC_SW_PAD_CTL_PAD_GPIO_AD_B1_03 = PAD;
  IOMUXC_SW_PAD_CTL_PAD_GPIO_AD_B1_04 = PAD;
  IOMUXC_SW_PAD_CTL_PAD_GPIO_AD_B1_05 = PAD;
  IOMUXC_SW_PAD_CTL_PAD_GPIO_AD_B1_06 = PAD;
  IOMUXC_SW_PAD_CTL_PAD_GPIO_AD_B1_07 = PAD;
  IOMUXC_SW_PAD_CTL_PAD_GPIO_AD_B1_08 = PAD;
  IOMUXC_SW_PAD_CTL_PAD_GPIO_AD_B1_09 = PAD;
  IOMUXC_SW_PAD_CTL_PAD_GPIO_AD_B1_10 = PAD;
  IOMUXC_SW_PAD_CTL_PAD_GPIO_AD_B1_11 = PAD;
  IOMUXC_SW_PAD_CTL_PAD_GPIO_AD_B1_12 = PAD;
  IOMUXC_SW_PAD_CTL_PAD_GPIO_AD_B1_13 = PAD;
  IOMUXC_SW_PAD_CTL_PAD_GPIO_AD_B1_14 = PAD;
  IOMUXC_SW_PAD_CTL_PAD_GPIO_AD_B1_15 = PAD;

  IOMUXC_SW_PAD_CTL_PAD_GPIO_EMC_04 = PAD;
  IOMUXC_SW_PAD_CTL_PAD_GPIO_EMC_05 = PAD;
  IOMUXC_SW_PAD_CTL_PAD_GPIO_EMC_06 = PAD;

 // Initialize the bus state variables

  busLookup[BUS_NACT]  = 4; // 100
  busLookup[BUS_BAR]   = 1; // 001
  busLookup[BUS_IAB]   = 4; // 100
  busLookup[BUS_DWS]   = 2; // 010   // test without dws handling
  busLookup[BUS_ADAR]  = 1; // 001
  busLookup[BUS_DW]    = 4; // 100
  busLookup[BUS_DTB]   = 0; // 000
  busLookup[BUS_INTAK] = 4; // 100
  
//  IOMUXC_GPR_GPR26 &=0xffff0000; not needed in teensy 4.1, it's default

 //Serial.begin(115200);
  
  pinMode(Status_PIN, OUTPUT);
  pinMode(BT1_PIN,INPUT_PULLDOWN);
  pinMode(BT2_PIN,INPUT_PULLDOWN);
  pinMode(BT3_PIN,INPUT_PULLDOWN);
  pinMode(DIR2_PIN,OUTPUT);
  pinMode(RST_PIN,OUTPUT);
  pinMode(MSYNC_PIN,INPUT_PULLDOWN);
    
  digitalWriteFast(RST_PIN,LOW);   //???????????
  digitalWriteFast(DIR2_PIN,HIGH); // A->B, TEENSY to INTV BUS
  
  for (long i=0; i<BINLENGTH; i++) {
    ROM[i]=0;
  }
 
 for (long i=0; i<RAMSIZE; i++) {
    RAM[i]=0;
  }

 for (int i=0; i<maxHacks; i++) {
  HACK[i]=0;
  HACK_CODE[i]=0;
 }
  
  while (!display.begin(SSD1306_SWITCHCAPVCC, SCREEN_ADDRESS));
  display.clearDisplay();
  display.setTextSize(2);
  display.setTextColor(1);
 
  display.setCursor(12, 1);
  display.print("RTO Cart");
  display.setTextSize(1);
  display.setCursor(110,22);
  display.print("1.0");
  display.display();
  //delay(500); // Pause for 2 seconds
  
  while (!sd.begin(SD_CONFIG)) 
  {
    display.clearDisplay();
    display.setCursor(0, 1);
    display.print("Insert SDCard");
    display.display();
  //  delay(1000);
  }

  for(int i=0;i<1280;i++){
    unsigned int dataW= splash[(i*2)+1] | (splash[i*2] << 8);
    ROM[i]=dataW;
  }
  slot=0;
  mapfrom[0]=0x0;
  mapto[0]=0x4ff;
  maprom[0]=0x5000;
  tipo[0]=0;
  page[0]=0;
  addrto[0]=0x54ff;
    
  display.clearDisplay();
  display.setCursor(0, 1);
  display.print("Press a button on RTO");
  display.display();
  resetCart();
  HandleBUS();
  
  Serial.println("exit splash");
  SelectBinFile();
  loadROM();
  display.clearDisplay();
  display.setCursor(0, 1);
  display.print("Emulating ROM:");
  display.setCursor(0,16);
  display.print(longfilename);
  if (hacks>0) {
    display.setCursor(92,1);
    display.setTextSize(1.5);
    display.print("(H)");
  }
  display.display();
  
  
}

void yield () {} //Get rid of the hidden function that checks for serial input and such.

void doReboot() {
  SCB_AIRCR = 0x05FA0004;
}

////////////////////////////////////////////////////////////////////////////////////
//                     RESET
////////////////////////////////////////////////////////////////////////////////////
void resetCart() {
 
  digitalWriteFast(Status_PIN,HIGH);
  Serial.println(digitalReadFast(MSYNC_PIN));

  do {
    digitalWriteFast(Status_PIN,digitalReadFast(MSYNC_PIN));
    digitalWriteFast(RST_PIN,HIGH);
    delay(6);
    if (digitalReadFast(MSYNC_PIN)==0) break;
    digitalWriteFast(RST_PIN,LOW);
    delay(2);
    if (digitalReadFast(MSYNC_PIN)==0) break;
    
  } while (digitalReadFast(MSYNC_PIN)==1);

//  do {
   digitalWriteFast(Status_PIN,digitalReadFast(MSYNC_PIN));
   digitalWriteFast(RST_PIN,LOW); 
 // } while (digitalReadFast(MSYNC_PIN)==0);
  
 
  Serial.println(digitalReadFast(MSYNC_PIN));
  
  digitalWriteFast(Status_PIN,LOW);
   //pinMode(RST_PIN,INPUT);
  //Serial.println("Reset");
}

////////////////////////////////////////////////////////////////////////////////////
//                     HANDLE BUS
////////////////////////////////////////////////////////////////////////////////////
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
void loop()
{
resetCart();  
HandleBUS();
}

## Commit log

2023-01-06 Add files via upload
    corrected the level shifter ICs to 74LVC245 instead of wrong typed 74LS245: WARNING! use only 74LVC245 chips, the other types could damage your Teensy becouse they output 5V instead of 3V3!
    [RTO_cart-B_Cu.gbl, RTO_cart-B_Mask.gbs, RTO_cart-B_Paste.gbp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]
2023-01-07 added ECS bank switching support
